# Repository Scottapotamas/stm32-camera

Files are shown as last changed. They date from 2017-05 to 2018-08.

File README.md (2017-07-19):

# stm32-camera

Existing products are either cameras which lack resolution and image quality (640x480 security cams that happen to have UART outputs), or are higher end expensive options geared towards computer vision for embedded hardware (openMV, PixyCam, etc).

This project seeks to provide higher quality still photos or short low-fps videos in an integrated device, allowing for greater integration flexibility whilst minimising power consumption.

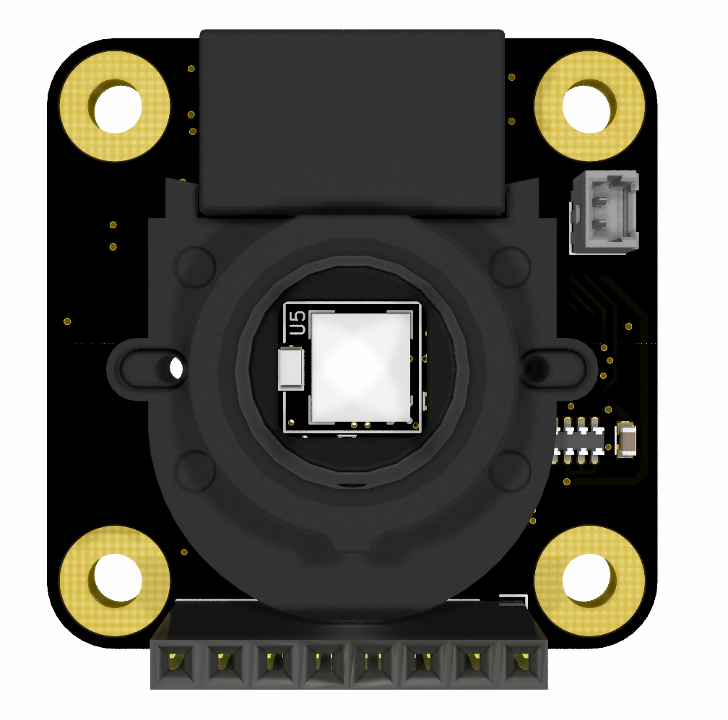
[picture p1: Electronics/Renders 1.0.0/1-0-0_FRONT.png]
Business at the front

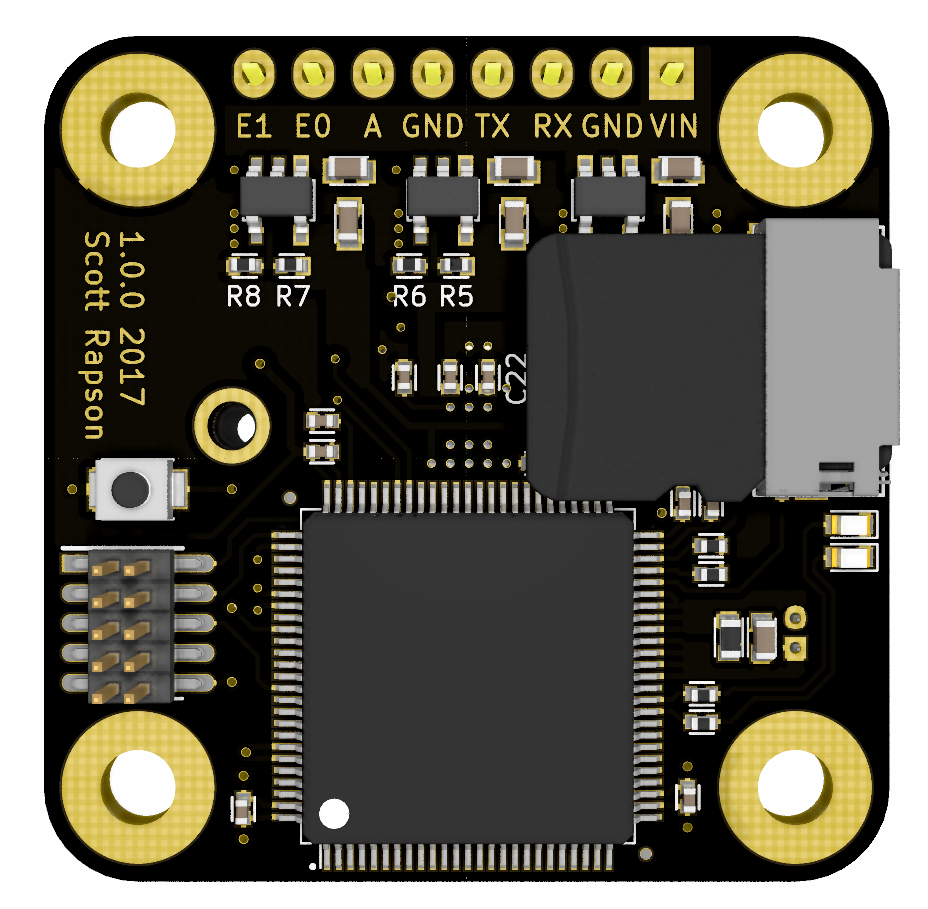
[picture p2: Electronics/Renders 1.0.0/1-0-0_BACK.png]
Party in the back


# Project Goals

- Sample a CMOS camera sensor using a microcontroller. Condition the data as appropriate, and hold images in memory.
- Allow upload of image data to the host over a serial, USB, or other connection.
- Aim to minimise current draw wherever possible, and design around the ability to 'deep-sleep' for maximum power savings.
- Support a wide range of lenses for different application requirements.
- Allow the host to control functionality such as exposure, capture modes, resolution, and power saving functionality.
- Cost less than $65
- Provide source for interfacing a host device like an Arduino/STM32.
- Provide software sources for the camera board to allow modified behaviour.

# Bonus Features

- Control either an onboard or off-board LED flash. Use a DAC output to drive it for variable brightness.
- Control a IR filter switch mechanism to add or subtract IR filtering automatically at night.
- Include hardware light sensing to detect ambient light without use of the camera (for IR filter switch, dynamic flash brightness, etc).
- Ability to store images or image sequences on disk, and/or copy them off later when the action dies down.

# Approach

- Small 32x32mm PCB with camera sensor, lens mount (uses 20mm spaced M2 screws), microcontroller.
- STM32F4 microcontroller interfaces to the sensor and provides power management, filter swaps, storage etc.
- The IO pinout is 2.54mm 8-way through hole. Accepts 4-14V DC input power. Has UART, and 3 high feature set expansion IO.
- Mounting hole pattern is somewhat backwards compatible with 28mm spaced M3 holes.

# Hardware Overview

- Its a 4 layer board due to the density of the fanout and smaller board package. 
- Min track width/clearance is 0.22mm and min via is 0.35mm. No blind or buried vias.
- While a bit tight, it should be fine with better 'budget' Chinese fabs. OSHPark would have absolutely no issues with it.
- Specific notes are in [the electronics folder](Electronics)

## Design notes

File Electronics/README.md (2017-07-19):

# Electronics Notes

General implementation notes during assignment and schematic capture. These are notes which don't make it onto the schematic due to length or relevance. Hopefully they might be useful during software dev.

# Microcontroller Pin Assignment

- I2C2 peripheral is used for SSCB interface (configuration registers).
- MCO (PA8) is used for the camera XCLK clock. Should clock at 24Mhz typical, 6Mhz minimum. This can be the HSI, HSE, a timer, etc.
- DCMI interface is used for main camera connection (includes HSYNC/VSYNC/PIXCK pins etc)
- PCLK is the camera strobe for 8-bit data on rising edge.
- PWDN is the camera power down signal (active high). Connected to PE3.
- RES is camera reset signal (active low). Connected to PE2
- SDIO interface is used in 4-bit mode for SD card. In theory, we should be able to write images to the SD card at highish speed, then allow the host to pull them off later if needed.
- SWD with SWO is enabled explicitly. Plan on using CORTEX 10-pin header.
- HSE clock included. Probably use a 16MHz CERALOCK instead of usual 8MHz?
- DAC2 is proposed for use with a flash driver. Ideally don't use PWM as switching noise is potentially visible, but that same pin can also be an analog input, PWM output or general GPIO.

# Sensor Specifics

## Power Down Options

| Hardware Control  | Software Control |
| --- | --- |
| PWDN is pulled high to stop the clock  | i2c commands available but doesn't stop everything (clocks) |
| Power draw is apparently 15uA.  | Registers are retained but draws 1mA.  |

Later on in the datasheet, this is conflicted by:

> For OV2640, there have big power down current, so power down mode is not supported by OV2640 for power saving.

The lower voltage LDO's have their EN line connected to the micro for more granular/forceful control.
I'll likely just use hardware control as long as it configures fast enough.

## Reset

A full hardware reset is performed when RESETB goes low.

There is also reset via the i2c interface.

## Other lines

- The datasheet states that strobe mode allows it to operate with an external flash and(/or?) LED. 
- The pinmap guide states this defaults as an input, but is the flash control output.
- A STM32 GPIO is connected instead of flash driver (at least to know if the camera wants a flash, probably redundant info by the time we see it)

# SD Card

# IR Cut Filter Switcher

As far as I can tell, its a bistable solenoid which moves the IR cut filter infront or away from the sensor.

## Theory

The [aliexpress page I got my samples from](https://www.aliexpress.com/item/HD-3MP-IR-CUT-filter-M12-lens-Metal-mount-double-filter-switcher-for-cctv-camera-IRCUT/32785570950.html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 ) has no real information other than images (but hey, $2.50AUD).

This [ebay page](http://www.ebay.com/itm/400938137287) seems to have more info (copied below)

- Working Voltage: 5V-18V
- Rated Current: 0.2A
- Screw thread interface: M12 Mount (MTV / C)
- Switcher Type: Pendulum Switcher
- Filter: Phosphate Filter
- Glass Size: 11*9.3mm
- Hole Spacing: 20mm
- Total length: 30mm. Inner Diameter: 15mm

I found another page with similar looking units which states the following:

- Start voltage: 1.8V±10%
- Applied voltage: 3.0V±10%
- Driver pulse width: 50ms
- Trigger current: 100mA or less
- Working current: 200mA or less

~~If the filter needs to be held in place during aquisition then some interesting software might need to manage the power consumption cleverly.~~ Pendulum switching means a short pulse high or low to set and forget. Drive with inverted polarity to change back.
This seems to vary between modules. Some of the other samples I received later *are* spring loaded.

It appears the units I recieved use a 1.25mm pitch molex(?) 2-pin connector. 
I'm pretty sure its molex because locking tab instead of slot. 
Seems like a Picoblade connector.

## Testing

Tests with bench supply show switching latches setting after power is removed.

With the supply set to 3.000V, the minimum current which triggers a full switch is 60mA. At 40mA and above, it appears to half-hold and reset on removal of power. Below 40mA nothing happens.

Switching would not occur at 2.0V. At 2.5V 50mA was able to activate the shutter, but 60-70mA was more reliable.

At 3.250V (rough design target for regulator and hence micro VDD) 45mA was enough to trigger a switch but sounded 'slower'. It seems the solenoid will draw 54mA, or 0.175W.

As some of these cameras will be in potentially extreme outdoor environments, a switching unit was cooled to -10°C and tested. 
At the same 3.250V, it requires 60mA to switch (0.195W). 

## Decision

It is unclear how the power requirements might change with manufacturing tolerances, temp cycling etc. Effects such as stiction etc haven't been tested for.

A 100mA spec'ed H-Bridge driver or equiv is probably the route to go.

As this eats a lot of room on the board using even small H-bridge drivers, and cost is a luxury, I'm strongly considering using multiple parallel GPIO pins (shared port for bitwise simultaneous control) to allow for push pull drive. As we only need short impulses this seems reasonable.

Unclear if the body diodes in the micro will be happy with this arrangement.

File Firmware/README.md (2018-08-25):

# Software Notes

General implementation notes during development. Some hardware related notes are built in here for people unfamiliar with STM32 or the programming ecosystem for ARM micros.

# Software Development and Debugging

## Toolchain and Install

I use the [SW4 System Workbench for STM32](http://www.openstm32.org/System+Workbench+for+STM32) for development and debugging. Follow the install instructions from openstm and everything should be reasonably easy to get working. The Eclipse project includes the config file for the debugging setup with both STLink and J-Link.

If you use a STLink programmer (either standalone or on a ST Discovery/Nucleo board) this should be all you need.

I use the SEGGER J-Link, so installing the J-Link software and the Eclipse plugin (Use Eclipse's "Install new software" and use the http://gnu-mcu-eclipse.netlify.com/v4-neon-updates source. I only install the J-Link plugin)

## Importing and navigating source

Import the project file in the stm32-camera folder. Code in [Src](stm32-camera\Src) is applicable to the project, everything else is either Eclipse or CubeMX generated. 

The software is based heavily on the framework I use at work, and uses a (custom) simple task scheduler and series of (HSM) state machines. The app_state_machines folder contains the highest level tasks and handles events.

app_drivers contains the mid-level functional code to handle individual software level tasks like or manage a series of hardware interfaces (controlling the camera requires use of the DCMI, GPIO and timer/mco functions for example).

app_hal is the 'low-level' hardware interface code. This mostly wraps the STM32 HAL library calls in human friendly functions for convenience. This layer can/should be split away form the rest of the code to provide unit tests, or reduce the effort for porting to other platforms etc.

## Flashing/Debugging Hardware

The board has a CORTEX 1.25mm pitch 2x5 connector for flashing and debugging over SWD. Pinout is below. Pin 7 is designed as the locating pin/key, and some connectors or headers don't have the pin/socket.

| Row 1 Pins | Row 2 Pins |
| --- | --- |
| 1 - VTref | 2 - SWDIO		|
| 3 - GND 	| 4 - SWDCLK	|
| 5 - GND 		| 6 - SWO		|
| 7 - Key/NC	| 8 - NC		|
| 9 - GNDDetect | 10 - NRST		|

I use a J-Link programmer, but the ST-Link/VS ISOL is also another choice I like which uses the same 20-pin jtag header.

Adafruit sell a [suitable cable](https://www.adafruit.com/product/1675), and [adaptor board](https://www.adafruit.com/product/2094) for standard 2.54mm 20-pin. I got an [adapter from OLIMEX](https://www.olimex.com/Products/ARM/JTAG/ARM-JTAG-20-10/) which is a bit nicer for direct connection to the programmer.

Using a STM32 discovery as a programmer, or the cheap chinese STLink clones will also work, but you will need to make a suitable cable.

## STM32 CubeMX

CubeMX is designed to take the effort out of setting up and configuring the peripherals and pins on STM32 micros. This is pretty standard in many STM based projects and should be easy enough to follow.

If pinouts are being changed or settings modified, make sure the changes are actually reflected in the app_hal source as I don't use the CubeMX generated wrappers for init etc. By rolling (mostly) the same code in my own hal layer, there are fewer issues with regenerating cubemx and allows for dynamic init/deinit of peripherals to reduce power when they are unused.

## Unit Tests

TODO: describe how to run tests

TODO: actually add a testing framework and write tests...

## Firmware Flashing without SWD

The microcontroller supports firmware updates using the internal read-only bootloader which is present on all STM32 chips. This functionality means the board is 'unbrickable'. This same functionality allows a 'host' microcontroller to update the camera board firmware in the field.

Normally the BOOT0 pin is held high during startup and the micro will enter the bootloader. On this board, the micro has the ability to enter the bootloader from software, which is done by charging a capacitor then calling for a reboot. The cap holds BOOT0 high long enough for the STM upgrade utility to start.

The microcontroller can be commanded to enter this mode through the command line. TODO:by holding the user-button for 5 seconds during boot.

A UART cable can be used with the [ST Demonstration Flasher32 Application DB2875](http://www.st.com/en/development-tools/flasher-stm32.html) to perform firmware updates with a PC.

The protocol for the bootloader is defined in the [ST AN3155 appnote](http://www.st.com/content/ccc/resource/technical/document/application_note/51/5f/03/1e/bd/9b/45/be/CD00264342.pdf/files/CD00264342.pdf/jcr:content/translations/en.CD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).

If you've flashed some software that prevents the micro from being able to start the upgrade proceedure, you can manually force BOOT0 high by conecting the outside side of C28 to 3.3V (or use SWD and a real programmer).

___

# Clock Speed and Performance

The F429 was originally selected due to DCMI, SDIO peripherals, and best internal RAM/$ for the QFP100 package.

As one of the goals of this board is low quiescent power consumption, I've made an effort to build tools early on to validate power usage.

## SLEEP Mode

Low hanging fruit (micro into sleep mode when waiting for events) makes the largest difference, cutting the 220mW starting draw to ~110mW. 

TODO: Consider not waking on systick interupts?

## 'Underclocking' the core

By adding a CPU load measurement, I was able to watch task requirements and processing time, and drop the clock speed of the micro.

By measuring the power consumption (micro powered directly from lab supply) against clock frequency I noticed how substantial savings could be for idle operation. 

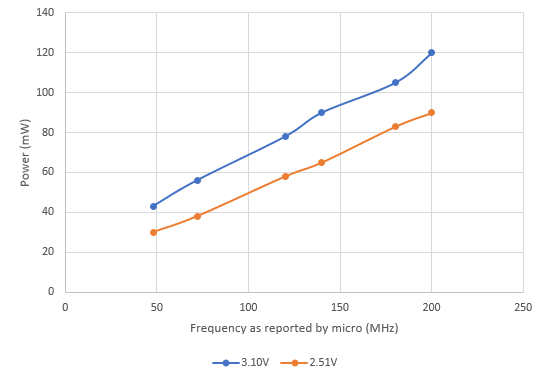
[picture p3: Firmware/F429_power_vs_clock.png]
Core Speed vs Power


From here, dynamic clock speed handling was developed to help reduce wasted energy when we aren't doing much.

## STOP mode

When we know (or the host controlling us) that we aren't needed, STOP mode represents another drop in average idle consumption by stopping clocks and peripherals altogether.

Intend for wake on the USART1 interupt. Need to profile power consumption and startup times to see if this is acceptable.

# SD Card

We use the SDIO interface in 4-bit mode.

This thread discusses using DMA for high performance non-blocking use.
https://community.st.com/thread/39133-high-performance-sdiosdmmc-driver-using-dma-for-freertos-anyone

Also this tutorial: http://thehackerworkshop.com/?p=1103

Detection relies on the internal pullup on that GPIO pin.

# Other notes

https://github.com/nothings/stb

Seems like a possible option for direct jpeg manipulation.

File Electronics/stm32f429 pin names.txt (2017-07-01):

TRACECLK/SPI4_SCK/SAI1_MCLK_A/ETH_MII_TXD3/FMC_A23
TRACED0/SAI1_SD_B/FMC_A19
TRACED1/SPI4_NSS/SAI1_FS_A/FMC_A20/DCMI_D4/LCD_B0
TRACED2/TIM9_CH1/SPI4_MISO/SAI1_SCK_A/FMC_A21/DCMI_D6/LCD_G0
TRACED3/TIM9_CH2/SPI4_MOSI/SAI1_SD_A/FMC_A22/DCMI_D7/LCD_G1
VBAT
EVENTOUT
EVENTOUT
EVENTOUT
VSS
VDD
EVENTOUT
EVENTOUT
NRST
OTG_HS_ULPI_STP/FMC_SDNWE
ETH_MDC/SPI2_MISO/I2S2ext_SD/OTG_HS_ULPI_DIR/ETH_MII_TXD2/FMC_SDNE0
SPI2_MISO/I2S2ext_SD/OTG_HS_ULPI_DIR/ETH_MII_TXD2/FMC_SDNE0
SPI2_MOSI/I2S2_SD/OTG_HS_ULPI_NXT/ETH_MII_TX_CLK/FMC_SDCKE0
VDD
VSSA
VREF+
VDDA
TIM2_CH1/TIM2_ETR/TIM5_CH1/TIM8_ETR/USART2_CTS/UART4_TX/ETH_MII_CRS
TIM2_CH2/TIM5_CH2/USART2_RTS/UART4_RX/ETH_MII_RX_CLK/ETH_RMII_REF_CLK
TIM2_CH3/TIM5_CH3/TIM9_CH1/USART2_TX/ETH_MDIO
TIM2_CH4/TIM5_CH4/TIM9_CH2/USART2_RX/OTG_HS_ULPI_D0/ETH_MII_COL/LCD_B5
VSS
VDD
SPI1_NSS/SPI3_NSS/I2S3_WS/USART2_CK/OTG_HS_SOF/DCMI_HSYNC/LCD_VSYNC
TIM2_CH1/TIM2_ETR/TIM8_CH1N/SPI1_SCK/OTG_HS_ULPI_CK
TIM1_BKIN/TIM3_CH1/TIM8_BKIN/SPI1_MISO/TIM13_CH1/DCMI_PIXCLK/LCD_G2
TIM1_CH1N/TIM3_CH2/TIM8_CH1N/SPI1_MOSI/TIM14_CH1/ETH_MII_RX_DV/ETH_RMII_CRS_DV
ETH_MII_RXD0/ETH_RMII_RXD0
ETH_MII_RXD1/ETH_RMII_RXD1
TIM1_CH2N/TIM3_CH3/TIM8_CH2N/LCD_R3/OTG_HS_ULPI_D1/ETH_MII_RXD2
TIM1_CH3N/TIM3_CH4/TIM8_CH3N/LCD_R6/OTG_HS_ULPI_D2/ETH_MII_RXD3
EVENTOUT
TIM1_ETR/UART7_Rx/FMC_D4
TIM1_CH1N/UART7_Tx/FMC_D5
TIM1_CH1/FMC_D6
TIM1_CH2N/FMC_D7
TIM1_CH2/SPI4_NSS/FMC_D8/LCD_G3
TIM1_CH3N/SPI4_SCK/FMC_D9/LCD_B4
TIM1_CH3/SPI4_MISO/FMC_D10/LCD_DE
TIM1_CH4/SPI4_MOSI/FMC_D11/LCD_CLK
TIM1_BKIN/FMC_D12/LCD_R7
TIM2_CH3/I2C2_SCL/SPI2_SCK/I2S2_CK/USART3_TX/OTG_HS_ULPI_D3/ETH_MII_RX_ER/LCD_G4
TIM2_CH4/I2C2_SDA/USART3_RX/OTG_HS_ULPI_D4/ETH_MII_TX_EN/ETH_RMII_TX_EN/LCD_G5
VCAP_1
VDD
TIM1_BKIN/I2C2_SMBA/SPI2_NSS/I2S2_WS/USART3_CK/CAN2_RX/OTG_HS_ULPI_D5/ETH_MII_TXD0/ETH_RMII_TXD0/OTG_HS_ID
TIM1_CH1N/SPI2_SCK/I2S2_CK/USART3_CTS/CAN2_TX/OTG_HS_ULPI_D6/ETH_MII_TXD1/ETH_RMII_TXD1
TIM1_CH2N/TIM8_CH2N/SPI2_MISO/I2S2ext_SD/USART3_RTS/TIM12_CH1/OTG_HS_DM
RTC_REFIN/TIM1_CH3N/TIM8_CH3N/SPI2_MOSI/I2S2_SD/TIM12_CH2/OTG_HS_DP
USART3_TX/FMC_D13
USART3_RX/FMC_D14
USART3_CK/FMC_D15/LCD_B3
USART3_CTS/FMC_A16
TIM4_CH1/USART3_RTS/FMC_A17
TIM4_CH2/FMC_A18
TIM4_CH3/FMC_D0
TIM4_CH4/FMC_D1
TIM3_CH1/TIM8_CH1/I2S2_MCK/USART6_TX/SDIO_D6/DCMI_D0/LCD_HSYNC
TIM3_CH2/TIM8_CH2/I2S3_MCK/USART6_RX/SDIO_D7/DCMI_D1/LCD_G6
TIM3_CH3/TIM8_CH3/USART6_CK/SDIO_D0/DCMI_D2
MCO2/TIM3_CH4/TIM8_CH4/I2C3_SDA/I2S_CKIN/SDIO_D1/DCMI_D3
MCO1/TIM1_CH1/I2C3_SCL/USART1_CK/OTG_FS_SOF/LCD_R6
TIM1_CH2/I2C3_SMBA/USART1_TX/DCMI_D0
TIM1_CH3/USART1_RX/OTG_FS_ID/DCMI_D1
TIM1_CH4/USART1_CTS/CAN1_RX/LCD_R4/OTG_FS_DM
TIM1_ETR/USART1_RTS/CAN1_TX/LCD_R5/OTG_FS_DP
JTMS-SWDIO
VCAP_2
VSS
VDD
JTCK-SWCLK
JTDI/TIM2_CH1/TIM2_ETR/SPI1_NSS/SPI3_NSS/I2S3_WS
SPI3_SCK/I2S3_CK/USART3_TX/UART4_TX/SDIO_D2/DCMI_D8/LCD_R2
I2S3ext_SD/SPI3_MISO/USART3_RX/UART4_RX/SDIO_D3/DCMI_D4
SPI3_MOSI/I2S3_SD/USART3_CK/UART5_TX/SDIO_CK/DCMI_D9
CAN1_RX/FMC_D2
CAN1_TX/FMC_D3
TIM3_ETR/UART5_RX/SDIO_CMD/DCMI_D11
SPI2_SCK/I2S2_CK/USART2_CTS/FMC_CLK/DCMI_D5/LCD_G7
USART2_RTS/FMC_NOE
USART2_TX/FMC_NWE
SPI3_MOSI/I2S3_SD/SAI1_SD_A/USART2_RX/FMC_NWAIT/DCMI_D10/LCD_B2
USART2_CK/FMC_NE1/FMC_NCE2
JTDO/TRACESWO/TIM2_CH2/SPI1_SCK/SPI3_SCK/I2S3_CK
NJTRST/TIM3_CH1/SPI1_MISO/SPI3_MISO/I2S3ext_SD
TIM3_CH2/I2C1_SMBA/SPI1_MOSI/SPI3_MOSI/I2S3_SD/CAN2_RX/OTG_HS_ULPI_D7/ETH_PPS_OUT/FMC_SDCKE1/DCMI_D10
TIM4_CH1/I2C1_SCL/USART1_TX/CAN2_TX/FMC_SDNE1/DCMI_D5
TIM4_CH2/I2C1_SDA/USART1_RX/FMC_NL/DCMI_VSYNC
BOOT0
TIM4_CH3/TIM10_CH1/I2C1_SCL/CAN1_RX/ETH_MII_TXD3/SDIO_D4/DCMI_D6/LCD_B6
TIM4_CH4/TIM11_CH1/I2C1_SDA/SPI2_NSS/I2S2_WS/CAN1_TX/SDIO_D5/DCMI_D7/LCD_B7
TIM4_ETR/UART8_RX/FMC_NBL0/DCMI_D2
UART8_Tx/FMC_NBL1/DCMI_D3

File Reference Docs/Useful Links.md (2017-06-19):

# Omnivision documentation

- Found the 'confidential' OV hardware and software appnotes, along with the SSCB (i2c like) settings interface.
- Found some unattributed c code which has the best register maps I've found so far.
- Won't run on hardware, but great reference for control over camera functions.

# OV2640 Camera Module under ChibiOS on the STM32F4-Discovery Board

http://www.elektricks.net/ov2640-camera-module-under-chibios-on-the-stm32f4-discovery-board/

- Provided source
- Uses chibiOS
- Uses DCMI, shows pinout and wiring to F4 disco
- Blog post archived in .zip.

# OV2640 Camera module on STM32 (without DCMI interface)

http://qyx.krtko.org/projects/ov2640_stm32/
https://github.com/iqyx/ov2640-stm32

- Main.c code in ref folder.
- Blog archived in zip.
- Uses chibiOS
- Doesn't use DCMI (because chibiOS had poor support for it back then)
- Uses DMA, discusses i2c config.

# OV2640 Linux driver

- Has additional notes for register settings etc.
- Source .c in folder.

# General Notes

0xFF 0xD8 is the start of a JPEG frame.
0xFF 0xD9 is the end of the JPEG frame.

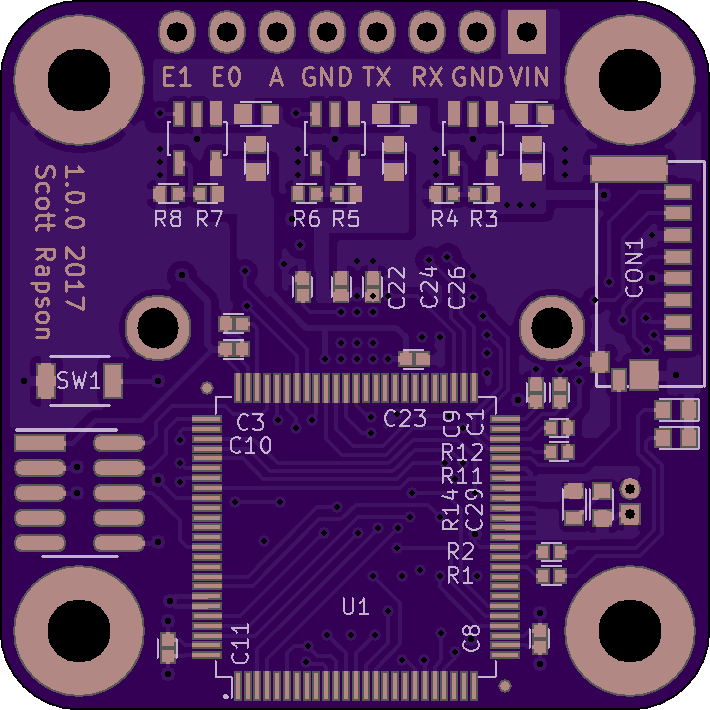
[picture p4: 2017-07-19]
Electronics/Renders 1.0.0/osh-check-back.png

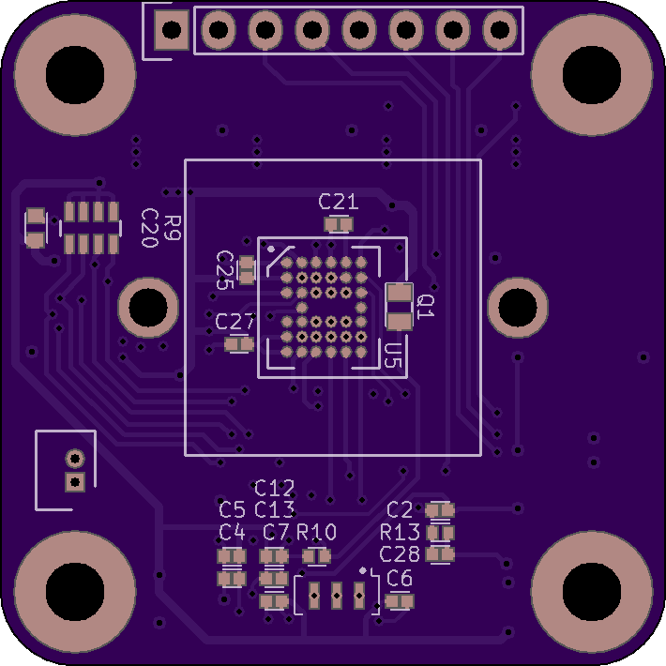
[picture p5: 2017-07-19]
Electronics/Renders 1.0.0/osh-check-front.png

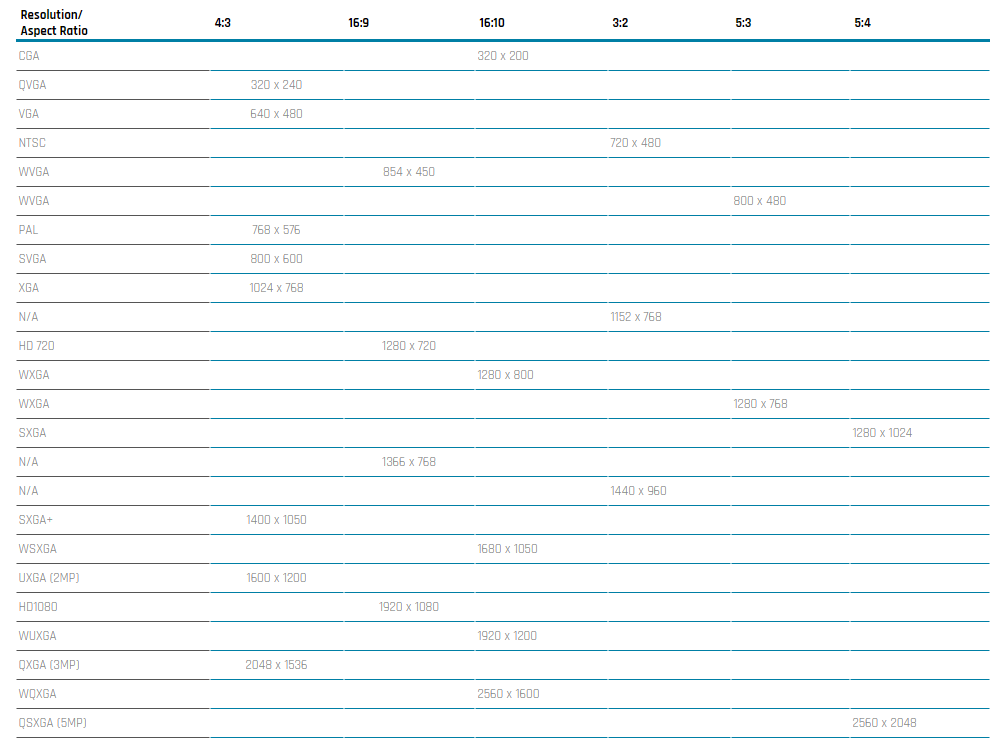
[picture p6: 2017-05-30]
Reference Docs/Resolution table.PNG

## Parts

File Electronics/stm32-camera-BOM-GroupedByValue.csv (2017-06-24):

Title:
Rev: | A
Source: | F:\Projects\stm32-camera\Electronics\stm32-camera.sch
Date: | 25/06/2017 1:23:17 AM
Component Count: | 53
Ref | Qty | Value | Description | Manf | Manf# | Installed | Footprint
C1, C3, C4, C12, C20, C24 | 6 | 1UF_X5R_1005M | CAP, MLCC, X5R, 1UF, 35V, 0402, 1005M | TDK | C1005X5R1V105K050BC |  | CAPC1005X60N
C14, C15, C16, C17, C18, C19 | 6 | 2.2UF_X7R_1608M | CAP, MLCC, X7R, 2.2UF, 50V, 0603 | MURATA | GRM188R61H225KE11D |  | CAPC1608X90L
C2, C5, C6, C7, C8, C9, C10, C11, C13, C21, C22, C25, C26, C27 | 14 | 100NF_X7R_1005M | CAP, MLCC, X7R, 100NF, 50V, 0402, 1005M | TDK | CGA2B3X7R1H104K050BB |  | CAPC1005X60N
C23 | 1 | 4.7UF_X5R_1608M | CAP, MLCC, X5R, 4.7UF, 16V, 0603 | TDK | C1608X5R1C475K080AC |  | CAPC1608X90L
CON1 | 1 | MOLEX_47309-2651 | Molex SMD Compact Micro SD Card Connector, Push-Pull Insertion, Floating Card | MOLEX | 47309-2651 |  | MOLEX_47309-2651
D1 | 1 | LED_GREEN_1608M | DIALIGHT ChipLED Green, 0603, 1608M | DIALIGHT | 5988070107F |  | LEDC1608X80L40N
D2 | 1 | LED_RED_1608M | DIALIGHT ChipLED Red, 0603, 1608M | DIALIGHT | 5988010107F |  | LEDC1608X80L40N
MP1 | 1 | M12_LENS_MOUNT_IR_SWITCHNG | M12x0.5 Lens Mount, Metal Body, M2-20mm holes, IR and Daylight Filter, Switchable | NOVOXY | UNKNOWN |  | M12x0.5_LENS_MOUNT_IR_SWITCHNG
P1 | 1 | HEADER_MALE_2MM_01X06 | Board-To-Board Connector, 2 mm, 6 Contacts, Header, Male, M22 Series, Through Hole, 1 Rows | HARWIN | M22-2510605 |  | HDRV6W50P200_6X1_1200X200H400
P2 | 1 | MOLEX_PICO_PTH_VERT_2_WAY | CONNECTOR, HEADER, 2POS, 1ROW, 1.25MM, PICOBLADE | MOLEX | 53047-0210 |  | MOLEX_PICOBLADE_53047-0210
Q1 | 1 | VEMT3700 | PHOTO TRANSISTOR, Vishay, NPN, 120degrees, 2-Pin PLCC package | VISHAY | VEMT3700-GS08 |  | VISHAY_VEMT3700N
R1, R2 | 2 | 1K_1005M | RESISTOR, THICK FILM, 1K, 63mW, 1%, 0402, 1005M | VISHAY | CRCW04021K00FKED |  | RESC1005X40N
R10 | 1 | 10K_1005M | RESISTOR, THICK FILM, 10K, 63mW, 1%, 0402, 1005M | VISHAY | CRCW040210K0FKED |  | RESC1005X40N
R11, R12 | 2 | 4K7_1005M | RESISTOR, THICK FILM, 4.7K, 125mW, 1%, 0402, 1005M | VISHAY | CRCW08054K70FKTA |  | RESC1005X40N
R3 | 1 | 51K_1005M | RESISTOR, THICK FILM, 51K, 63mW, 1%, 0402, 1005M | PANASONIC | ERA2AEB513X |  | RESC1005X40N
R4 | 1 | 82K_1005M | RESISTOR, THICK FILM, 82K, 100mW, 1%, 0402, 1005M | PANASONIC | ERJ2GEJ823X |  | RESC1005X40N
R5 | 1 | 47K_1005M | RESISTOR, THICK FILM, 47K, 63mW, 1%, 0402, 1005M | YAGEO | RC0402FR-0747KL |  | RESC1005X40N
R6 | 1 | 56K2_1005M | RESISTOR, THICK FILM, 56.2K, 63mW, 1%, 0402, 1005M | PANASONIC | ERA2AEB5622X |  | RESC1005X40N
R7 | 1 | 100K_1005M | RESISTOR, THICK FILM, 100K, 100mW, 1%, 0402, 1005M | PANASONIC | ERJ2RKF1003X |  | RESC1005X40N
R8 | 1 | 3K6_1005M | RESISTOR, THICK FILM, 3.6K, 100mW, 1%, 0402, 1005M | PANASONIC | ERJ2GEJ362X |  | RESC1005X40N
R9 | 1 | 47K_QUAD_ARRAY_1608M | RESISTOR, THICK FILM, 47K, 5%, 0603, 1608M, QUAD ARRAY | PANASONIC | EXB38V473JV |  | R_Array_Concave_4x1608M
U1 | 1 | STM32F429VET6 | ST STM32F429VET6, ARM Cortex-M4, 32bit, 180 MHz, 512 KB Flash, 256 KB SRAM, 100 Pins | ST MICROELECTRONICS | STM32F429VET6 |  | QFP50P1600X1600X160-100L25N
U2, U3, U4 | 3 | AP2210K-ADJ | AP2210K-ADJTRG1, Low Noise LDO Voltage Regulator, 300mA, Adjustable Voltage, 2%, 2.5 to 13.2 Vin, SOT23-5 | DIODES ZETEX | AP2210K-ADJTRG1 |  | SOT95P280X145-5L30N
U5 | 1 | OV02640-VL9A | OmniVision, Color, CMOS, Camera, 2.0 MP, UXGA 1/4" | OmniVision | OV02640-VL9A |  | OV2640_CSP_38
X1 | 1 | CSTCE8M00G55Z | Murata Ceramic Resonator, 8MHz Shear 33pF, 3-Pin SMT | Murata | CSTCE8M00G55Z-R0 |  | OSCSC-CSCTE-CERALOCK
X2 | 1 | SWD | Cortex-M Debug Connector, SWD, JTAG (Header 1.27mm pitch 10-way 2x5) | HARWIN | M50-3600542 |  | HARWIN_M50-3600542
Tool: | Eeschema (2017-03-19 revision 2637835a1)-makepkg
Script: | F:\Projects\ECAD\KiCad\scripts\BOM\bom\BOM-GroupedByValue.py

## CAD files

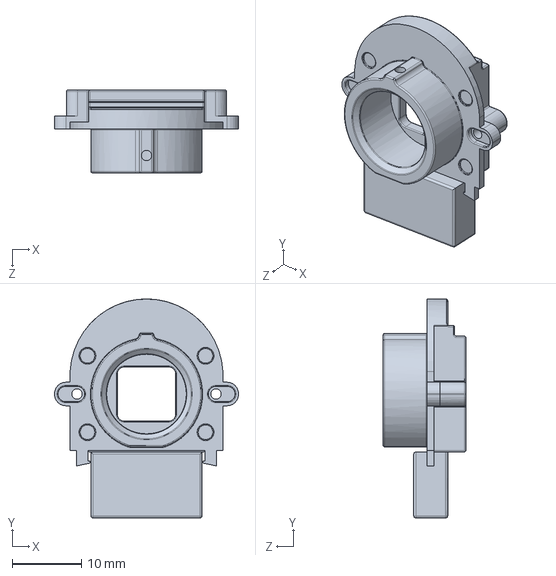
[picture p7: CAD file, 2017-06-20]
Mechanical/M12 Switchable IR Cut Filter Mount.SLDPRT
26.5 x 31.5 x 11.9 mm

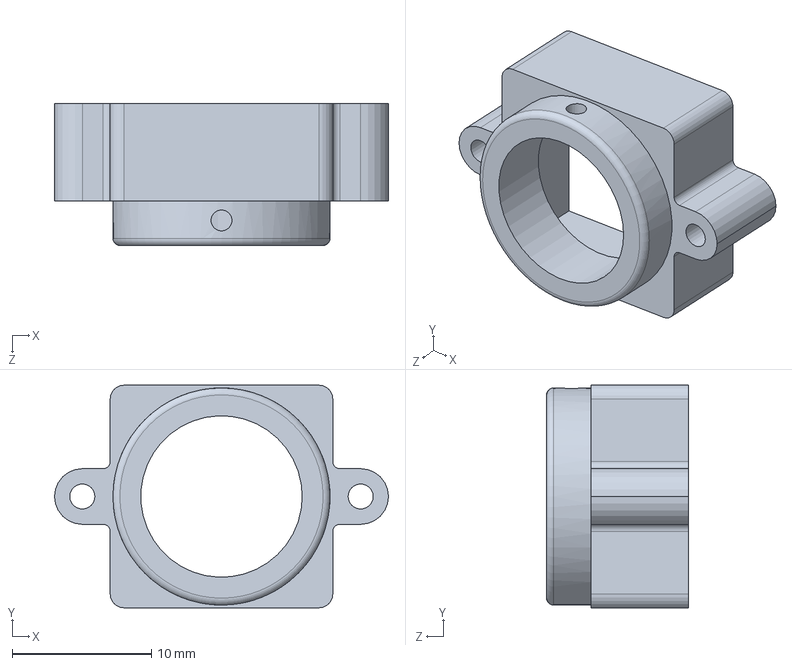
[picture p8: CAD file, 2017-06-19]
Mechanical/M12 Lens Mount Basic Block.SLDPRT
24.0 x 16.0 x 10.2 mm

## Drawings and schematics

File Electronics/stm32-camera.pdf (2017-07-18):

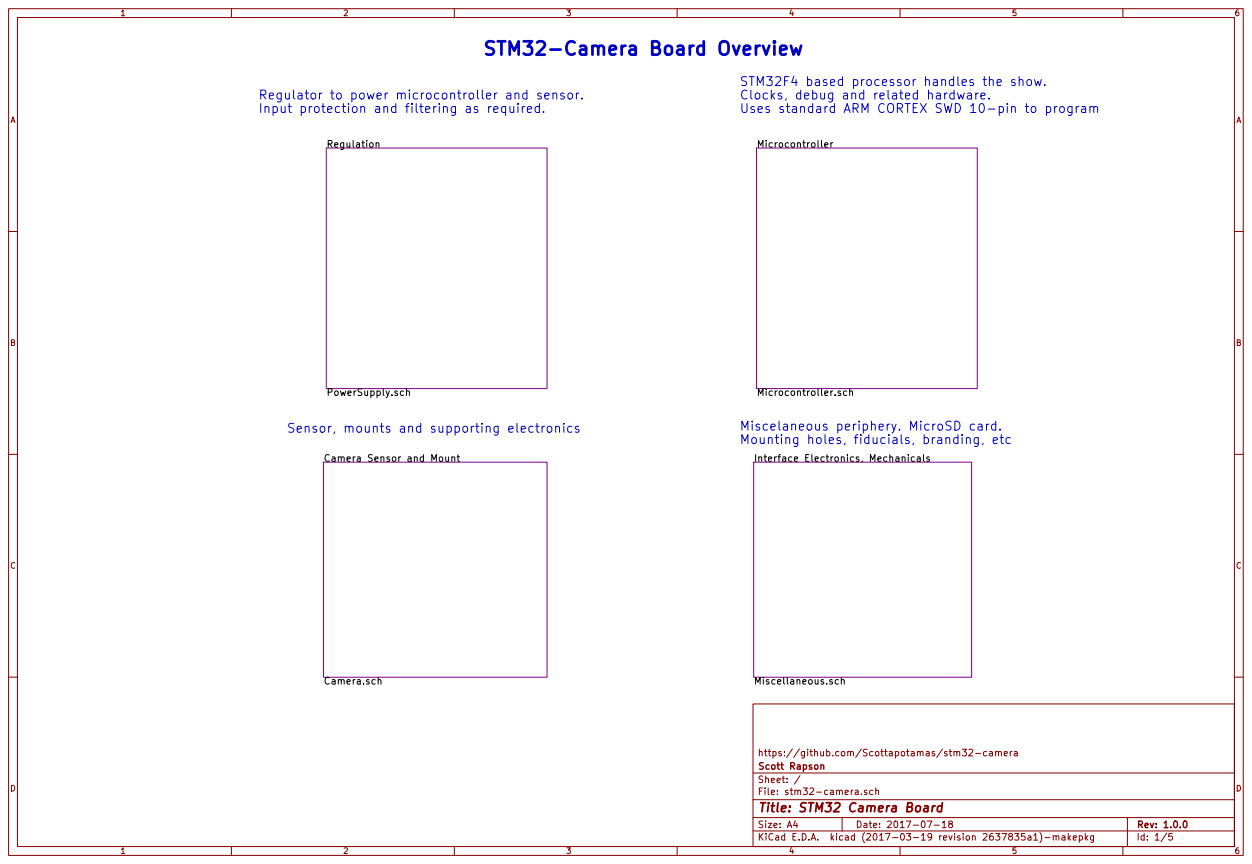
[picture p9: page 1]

Interface Electronics, Mechanicals Miscellaneous.sch STM32-Camera Board Overview

STM32F4 based processor handles the show.
Clocks, debug and related hardware.
Uses standard ARM CORTEX SWD 10-pin to program

Regulator to power microcontroller and sensor.
Input protection and filtering as required.

Microcontroller Microcontroller.sch Regulation

Sensor, mounts and supporting electronics

Miscelaneous periphery. MicroSD card.
Mounting holes, fiducials, branding, etc

Camera Sensor and Mount

https://github.com/Scottapotamas/stm32-camera
File: stm32-camera.sch Sheet: / Scott Rapson

Id: 1/5 Title: STM32 Camera Board

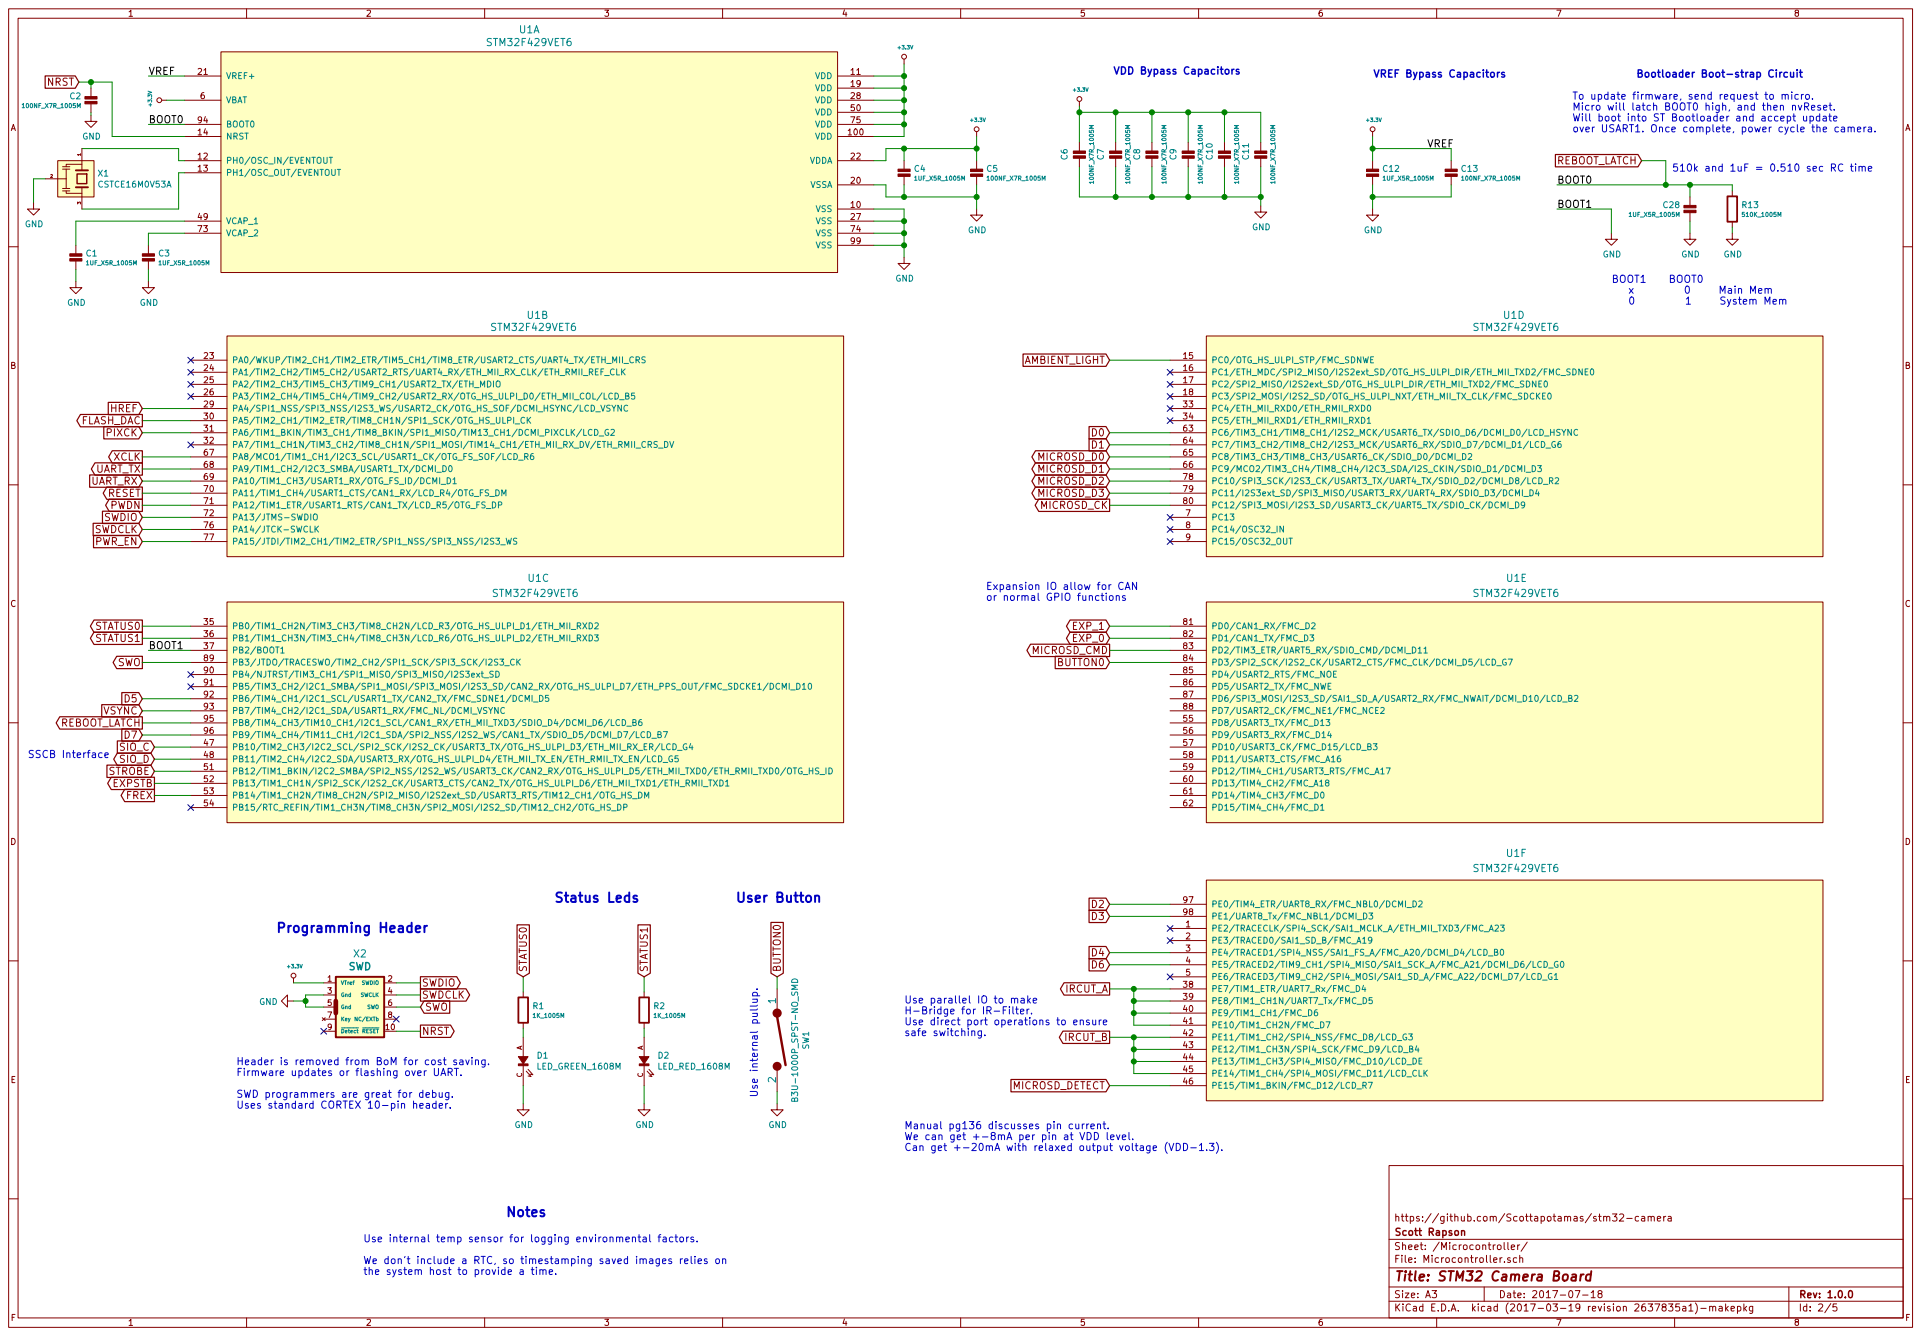
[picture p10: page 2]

Bootloader Boot-strap Circuit

BOOT1 GND To update firmware, send request to micro.
Micro will latch BOOT0 high, and then nvReset.
Will boot into ST Bootloader and accept update

over USART1. Once complete, power cycle the camera. GND

1UF_X5R_1005M510k and 1uF = 0.510 sec RC time

Expansion IO allow for CAN
or normal GPIO functions

User Button Use internal pullup.

Use parallel IO to make
H-Bridge for IR-Filter.
Use direct port operations to ensure

Header is removed from BoM for cost saving.
Firmware updates or flashing over UART.
SWD programmers are great for debug.
Uses standard CORTEX 10-pin header.

LED_RED_1608M Use internal temp sensor for logging environmental factors.

Manual pg136 discusses pin current.
We can get +-8mA per pin at VDD level.
Can get +-20mA with relaxed output voltage (VDD-1.3).

https://github.com/Scottapotamas/stm32-camera
File: Microcontroller.sch Sheet: /Microcontroller/ Scott Rapson

We don't include a RTC, so timestamping saved images relies on
the system host to provide a time.

Id: 2/5 Title: STM32 Camera Board

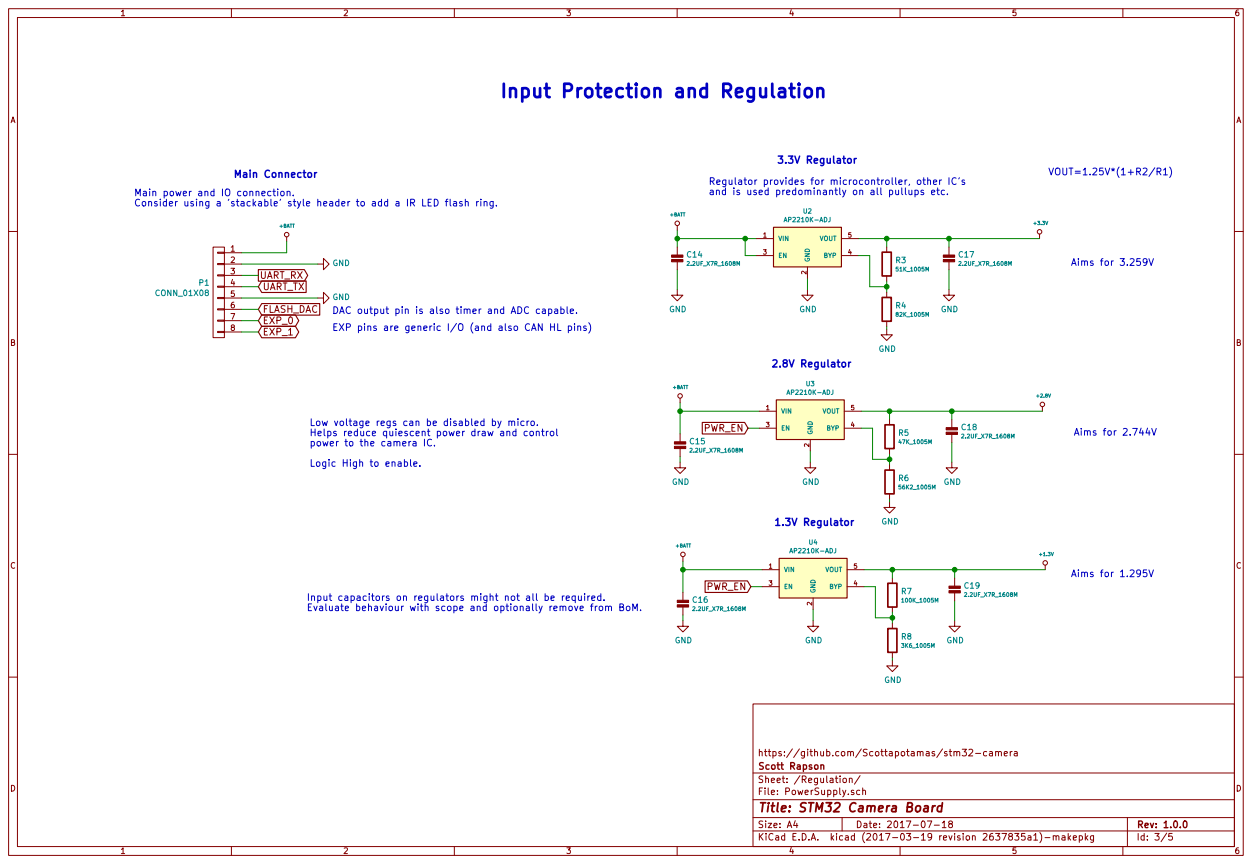
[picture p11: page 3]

Input Protection and Regulation

2 EN 3 BYP 4 VOUT 5 U2 AP2210K-ADJ VOUT=1.25V*(1+R2/R1) GND GND GND
2.2UF_X7R_1608M PWR_EN

Regulator provides for microcontroller, other IC's

Main power and IO connection.
Consider using a 'stackable' style header to add a IR LED flash ring. 1

EXP pins are generic I/O (and also CAN HL pins) GND
DAC output pin is also timer and ADC capable.

2 EN 3 BYP 4 VOUT 5 U3 AP2210K-ADJ

Low voltage regs can be disabled by micro.
Helps reduce quiescent power draw and control
power to the camera IC.
Logic High to enable.

2 EN 3 BYP 4 VOUT 5 U4 AP2210K-ADJ

Input capacitors on regulators might not all be required.
Evaluate behaviour with scope and optionally remove from BoM.

https://github.com/Scottapotamas/stm32-camera
Scott Rapson
Sheet: /Regulation/
File: PowerSupply.sch
Id: 3/5 Title: STM32 Camera Board

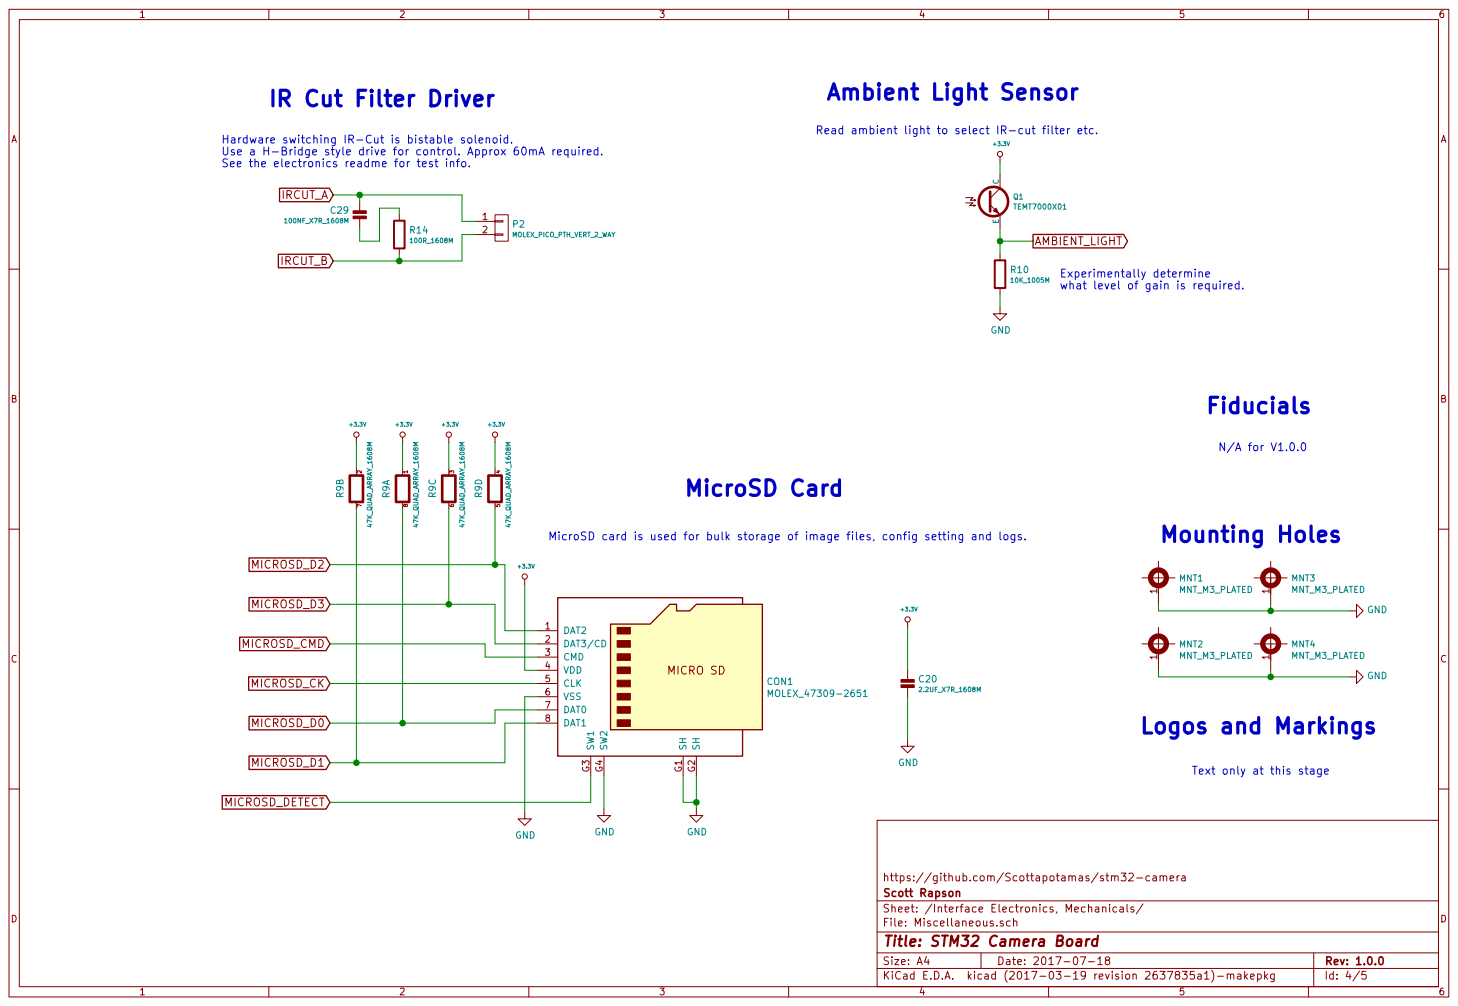
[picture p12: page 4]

Read ambient light to select IR-cut filter etc.

Hardware switching IR-Cut is bistable solenoid.
Use a H-Bridge style drive for control. Approx 60mA required.
See the electronics readme for test info.

what level of gain is required. R10
10K_1005M GND

1 MNT4 1MNT_M3_PLATED MNT2 MNT_M3_PLATED GND GND MICRO SD

Text only at this stage

https://github.com/Scottapotamas/stm32-camera
Scott Rapson
File: Miscellaneous.sch Sheet: /Interface Electronics, Mechanicals/
Id: 4/5 Title: STM32 Camera Board

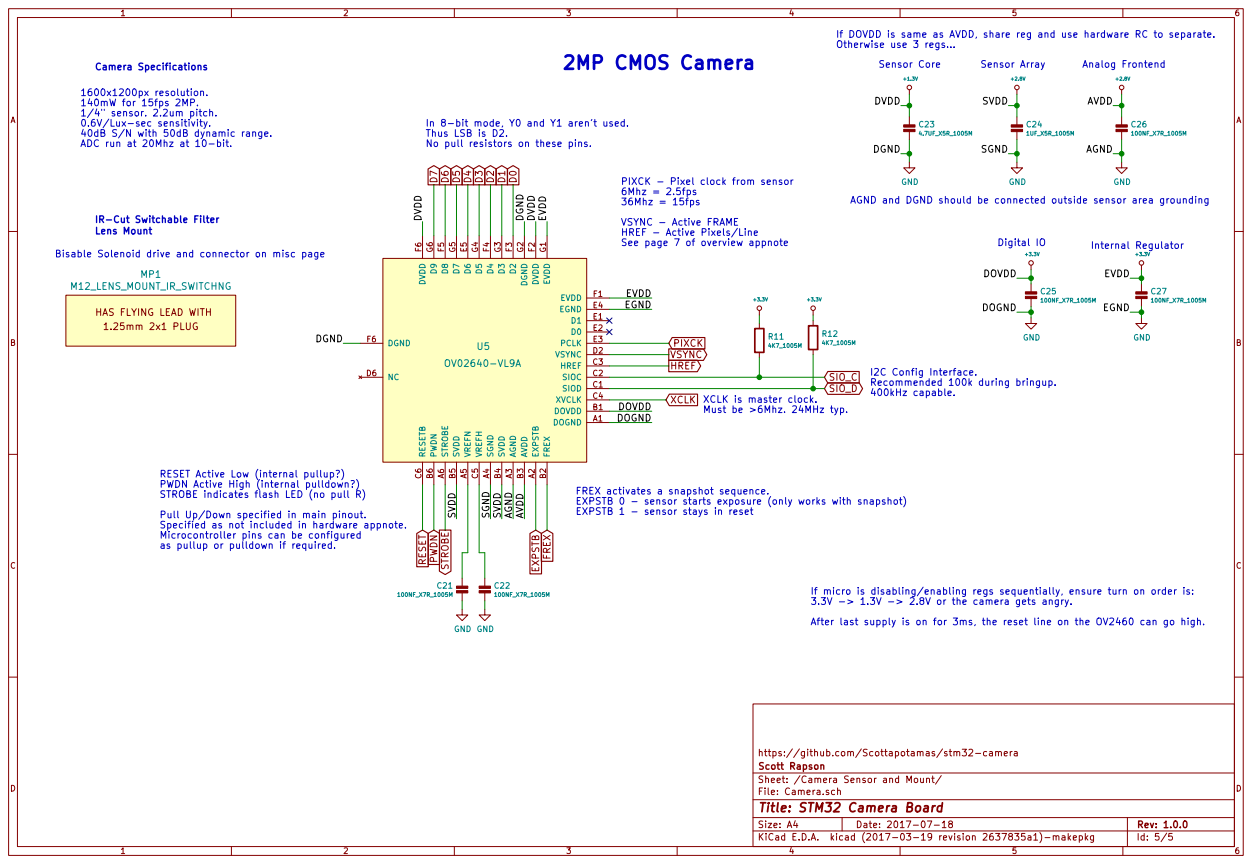
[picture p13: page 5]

If DOVDD is same as AVDD, share reg and use hardware RC to separate.

In 8-bit mode, Y0 and Y1 aren't used.
Thus LSB is D2.

100NF_X7R_1005M AGND and DGND should be connected outside sensor area grounding

See page 7 of overview appnote D7 D6 D5 D4 D3 D2 D1 D0

PIXCK - Pixel clock from sensor
6Mhz = 2.5fps
36Mhz = 15fps
VSYNC - Active FRAME
HREF - Active Pixels/Line

IR-Cut Switchable Filter Lens Mount Bisable Solenoid drive and connector on misc page

HAS FLYING LEAD WITH MP1 M12_LENS_MOUNT_IR_SWITCHNG

XCLK is master clock.

Must be >6Mhz. 24MHz typ. FREX EXPSTB

RESET Active Low (internal pullup?)
PWDN Active High (internal pulldown?)
STROBE indicates flash LED (no pull R)
Pull Up/Down specified in main pinout.
Specified as not included in hardware appnote.
Microcontroller pins can be configured
as pullup or pulldown if required.

FREX activates a snapshot sequence.
EXPSTB 0 - sensor starts exposure (only works with snapshot)
EXPSTB 1 - sensor stays in reset

If micro is disabling/enabling regs sequentially, ensure turn on order is:
3.3V -> 1.3V -> 2.8V or the camera gets angry.
After last supply is on for 3ms, the reset line on the OV2460 can go high.

https://github.com/Scottapotamas/stm32-camera
File: Camera.sch Sheet: /Camera Sensor and Mount/ Scott Rapson

Id: 5/5 Title: STM32 Camera Board

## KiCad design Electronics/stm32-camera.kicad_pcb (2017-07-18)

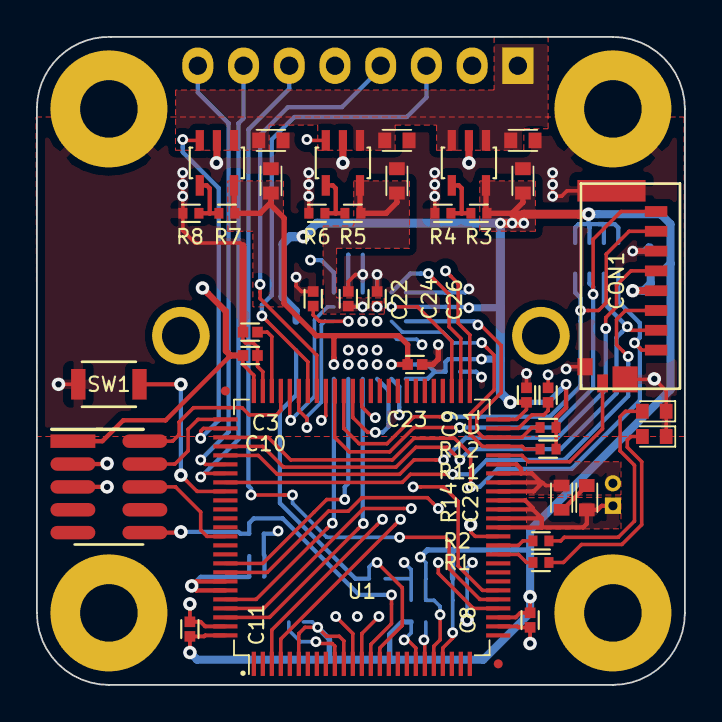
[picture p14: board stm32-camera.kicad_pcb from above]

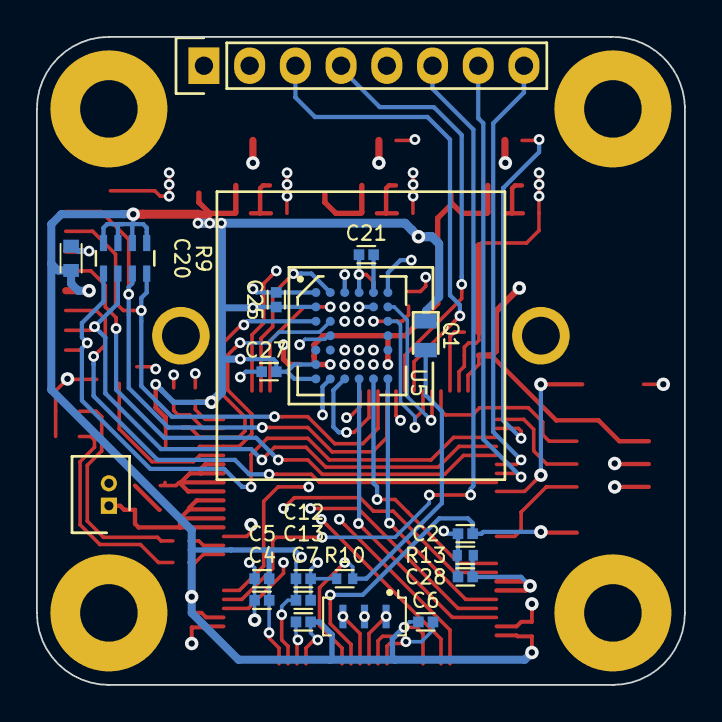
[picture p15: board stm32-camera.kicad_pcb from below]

Board: 4 copper layers, 36.0 x 36.0 mm, 62 parts (21 on the bottom side), 60 nets.

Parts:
C1, C3, C4, C12, C24, C28: 1UF_X5R_1005M; CAPC1005X60N
C2, C5, C6, C7, C8, C9, C10, C11, C13, C21, C22, C25, C26, C27: 100NF_X7R_1005M; CAPC1005X60N
C14, C15, C16, C17, C18, C19, C20: 2.2UF_X7R_1608M; CAPC1608X90L
C23: 4.7UF_X5R_1005M; CAPC1005X60N
C29: 100NF_X7R_1608M; CAPC1608X90L
CON1: MOLEX_47309-2651
D1: LED_GREEN_1608M; LEDC1608X80L40L
D2: LED_RED_1608M; LEDC1608X80L40L
MNT1, MNT2, MNT3, MNT4: MNT_M3_PLATED; MTGP650H330
MP1: M12_LENS_MOUNT_IR_SWITCHNG; M12x0.5_LENS_MOUNT_IR_SWITCHNG
P1: CONN_01X08; Socket_Strip_Straight_1x08
P2: MOLEX_PICO_PTH_VERT_2_WAY; MOLEX_PICOBLADE_53047-0210
Q1: TEMT7000X01; TEMT7000X
R1, R2: 1K_1005M; RESC1005X40N
R3: 51K_1005M; RESC1005X40N
R4: 82K_1005M; RESC1005X40N
R5: 47K_1005M; RESC1005X40N
R6: 56K2_1005M; RESC1005X40N
R7: 100K_1005M; RESC1005X40N
R8: 3K6_1005M; RESC1005X40N
R9: 47K_QUAD_ARRAY_1608M; R_Array_Concave_4x1608M
R10: 10K_1005M; RESC1005X40N
R11, R12: 4K7_1005M; RESC1005X40N
R13: 510K_1005M; RESC1005X40N
R14: 100R_1608M; RESC1608X50L
SW1: B3U-1000P_SPST-NO_SMD; B3U-1000P
U1: STM32F429VET6; QFP50P1600X1600X160-100L25L
U2, U3, U4: AP2210K-ADJ; SOT95P280X145-5L30N
U5: OV02640-VL9A; OV2640_CSP_38
X1: CSTCE16M0V53A; OSCSC-CSCTE-CERALOCK
X2: SWD; HARWIN_M50-3600542

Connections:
+1.3V: C19.1, C23.1, R7.1, U4.5, U5.F2, U5.F6
+2.8V: C18.1, C24.1, C26.1, R5.1, U3.5, U5.B3, U5.B4, U5.B5
+3.3V: C4.1, C5.1, C6.1, C7.1, C8.1, C9.1, C10.1, C11.1, C12.1, C13.1, C17.1, C20.1, C25.1, C27.1, CON1.4, Q1.C, R3.1, R9.1, R9.2, R9.3, R9.4, R11.1, R12.1, U1.6, U1.11, U1.19, U1.21, U1.22, U1.28, U1.50, U1.75, U1.100, U2.5, U5.B1, U5.F1, U5.G1, X2.1
+BATT: C14.1, C15.1, C16.1, P1.1, U2.1, U2.3, U3.1, U4.1
AMBIENT_LIGHT: Q1.E, R10.1, U1.15
BUTTON0: SW1.1, U1.84
D0: U1.63, U5.F3
D1: U1.64, U5.G3
D2: U1.97, U5.F4
D3: U1.98, U5.G4
D4: U1.3, U5.E5
D5: U1.92, U5.G5
D6: U1.4, U5.F5
D7: U1.96, U5.G6
EXPSTB: U1.52, U5.A2
EXP_0: P1.7, U1.82
EXP_1: P1.8, U1.81
FLASH_DAC: P1.6, U1.30
FREX: U1.53, U5.B2
GND: C1.2, C2.2, C3.2, C4.2, C5.2, C6.2, C7.2, C8.2, C9.2, C10.2, C11.2, C12.2, C13.2, C14.2, C15.2, C16.2, C17.2, C18.2, C19.2, C20.2, C21.2, C22.2, C23.2, C24.2, C25.2, C26.2, C27.2, C28.2, CON1.6, CON1.G1, CON1.G2, CON1.G4, D1.C, D2.C, MNT1.1, MNT2.1, MNT3.1, MNT4.1, P1.2, P1.5, R4.2, R6.2, R8.2, R10.2, R13.2, SW1.2, U1.10, U1.20, U1.27, U1.37, U1.74, U1.99, U2.2, U3.2, U4.2, U5.A1, U5.A3, U5.A4, U5.E4, U5.G2, X1.2, X2.3, X2.5
HREF: U1.29, U5.C3
IRCUT_A: C29.1, P2.1, U1.38, U1.39, U1.40, U1.41
IRCUT_B: P2.2, R14.2, U1.42, U1.43, U1.44, U1.45
MICROSD_CK: CON1.5, U1.80
MICROSD_CMD: CON1.3, U1.83
MICROSD_D0: CON1.7, R9.8, U1.65
MICROSD_D1: CON1.8, R9.7, U1.66
MICROSD_D2: CON1.1, R9.5, U1.78
MICROSD_D3: CON1.2, R9.6, U1.79
MICROSD_DETECT: CON1.G3, U1.46
NRST: C2.1, U1.14, X2.10
unnamed: C1.1, U1.49
unnamed: C3.1, U1.73
unnamed: C21.1, U5.A5
unnamed: C22.1, U5.C5
unnamed: C29.2, R14.1
unnamed: D1.A, R1.2
unnamed: D2.A, R2.2
unnamed: R3.2, R4.1, U2.4
unnamed: R5.2, R6.1, U3.4
unnamed: R7.2, R8.1, U4.4
unnamed: U1.12, X1.1
unnamed: U1.13, X1.3
PIXCK: U1.31, U5.E3
PWDN: U1.71, U5.B6
PWR_EN: U1.77, U3.3, U4.3
REBOOT_LATCH: C28.1, R13.1, U1.94, U1.95
RESET: U1.70, U5.C6
SIO_C: R11.2, U1.47, U5.C2
SIO_D: R12.2, U1.48, U5.C1
STATUS0: R1.1, U1.35
STATUS1: R2.1, U1.36
STROBE: U1.51, U5.A6
SWDCLK: U1.76, X2.4
SWDIO: U1.72, X2.2
SWO: U1.89, X2.6
UART_RX: P1.3, U1.69
UART_TX: P1.4, U1.68
VSYNC: U1.93, U5.D2
XCLK: U1.67, U5.C4

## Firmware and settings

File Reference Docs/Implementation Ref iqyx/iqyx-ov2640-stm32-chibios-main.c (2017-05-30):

/**
 * The following implementation is only a proof-of-concept that a OV2640
 * (or any other similar camera) can be easily connected to a MCU even without
 * the right hardware interface. Most F4 indeed does have the DCMI interface for
 * interfacing with such cameras, it was used only because the F4discovery
 * board was handy.
 *
 * My spaghetti code is dedicated to the public domain and I really hope that
 * nobody will ever use it. Some foreign parts use different licensing.
 */

#include "ch.h"
#include "hal.h"
#include "chprintf.h"

/* Allow chibios to use 64K of CCM memory on the F4. */
MemoryHeap ccm_heap;

/**
 * The following part is borrowed from the linux ov2640 driver. Some of the
 * registers are named but still there are many without any documentation.
 * Another possible source is the ArduCam project but it is not documented
 * and there are long arrays of magic values only.
 */

/*
 * ov2640 Camera Driver
 *
 * Copyright (C) 2010 Alberto Panizzo <maramaopercheseimorto@gmail.com>
 *
 * Based on ov772x, ov9640 drivers and previous non merged implementations.
 *
 * Copyright 2005-2009 Freescale Semiconductor, Inc. All Rights Reserved.
 * Copyright (C) 2006, OmniVision
 *
 * This program is free software; you can redistribute it and/or modify
 * it under the terms of the GNU General Public License version 2 as
 * published by the Free Software Foundation.
 */

#define VAL_SET(x, mask, rshift, lshift)  \
		((((x) >> rshift) & mask) << lshift)
/*
 * DSP registers
 * register offset for BANK_SEL == BANK_SEL_DSP
 */
#define R_BYPASS    0x05 /* Bypass DSP */
#define   R_BYPASS_DSP_BYPAS    0x01 /* Bypass DSP, sensor out directly */
#define   R_BYPASS_USE_DSP      0x00 /* Use the internal DSP */
#define QS          0x44 /* Quantization Scale Factor */
#define CTRLI       0x50
#define   CTRLI_LP_DP           0x80
#define   CTRLI_ROUND           0x40
#define   CTRLI_V_DIV_SET(x)    VAL_SET(x, 0x3, 0, 3)
#define   CTRLI_H_DIV_SET(x)    VAL_SET(x, 0x3, 0, 0)
#define HSIZE       0x51 /* H_SIZE[7:0] (real/4) */
#define   HSIZE_SET(x)          VAL_SET(x, 0xFF, 2, 0)
#define VSIZE       0x52 /* V_SIZE[7:0] (real/4) */
#define   VSIZE_SET(x)          VAL_SET(x, 0xFF, 2, 0)
#define XOFFL       0x53 /* OFFSET_X[7:0] */
#define   XOFFL_SET(x)          VAL_SET(x, 0xFF, 0, 0)
#define YOFFL       0x54 /* OFFSET_Y[7:0] */
#define   YOFFL_SET(x)          VAL_SET(x, 0xFF, 0, 0)
#define VHYX        0x55 /* Offset and size completion */
#define   VHYX_VSIZE_SET(x)     VAL_SET(x, 0x1, (8+2), 7)
#define   VHYX_HSIZE_SET(x)     VAL_SET(x, 0x1, (8+2), 3)
#define   VHYX_YOFF_SET(x)      VAL_SET(x, 0x3, 8, 4)
#define   VHYX_XOFF_SET(x)      VAL_SET(x, 0x3, 8, 0)
#define DPRP        0x56
#define TEST        0x57 /* Horizontal size completion */
#define   TEST_HSIZE_SET(x)     VAL_SET(x, 0x1, (9+2), 7)
#define ZMOW        0x5A /* Zoom: Out Width  OUTW[7:0] (real/4) */
#define   ZMOW_OUTW_SET(x)      VAL_SET(x, 0xFF, 2, 0)
#define ZMOH        0x5B /* Zoom: Out Height OUTH[7:0] (real/4) */
#define   ZMOH_OUTH_SET(x)      VAL_SET(x, 0xFF, 2, 0)
#define ZMHH        0x5C /* Zoom: Speed and H&W completion */
#define   ZMHH_ZSPEED_SET(x)    VAL_SET(x, 0x0F, 0, 4)
#define   ZMHH_OUTH_SET(x)      VAL_SET(x, 0x1, (8+2), 2)
#define   ZMHH_OUTW_SET(x)      VAL_SET(x, 0x3, (8+2), 0)
#define BPADDR      0x7C /* SDE Indirect Register Access: Address */
#define BPDATA      0x7D /* SDE Indirect Register Access: Data */
#define CTRL2       0x86 /* DSP Module enable 2 */
#define   CTRL2_DCW_EN          0x20
#define   CTRL2_SDE_EN          0x10
#define   CTRL2_UV_ADJ_EN       0x08
#define   CTRL2_UV_AVG_EN       0x04
#define   CTRL2_CMX_EN          0x01
#define CTRL3       0x87 /* DSP Module enable 3 */
#define   CTRL3_BPC_EN          0x80
#define   CTRL3_WPC_EN          0x40
#define SIZEL       0x8C /* Image Size Completion */
#define   SIZEL_HSIZE8_11_SET(x) VAL_SET(x, 0x1, 11, 6)
#define   SIZEL_HSIZE8_SET(x)    VAL_SET(x, 0x7, 0, 3)
#define   SIZEL_VSIZE8_SET(x)    VAL_SET(x, 0x7, 0, 0)
#define HSIZE8      0xC0 /* Image Horizontal Size HSIZE[10:3] */
#define   HSIZE8_SET(x)         VAL_SET(x, 0xFF, 3, 0)
#define VSIZE8      0xC1 /* Image Vertical Size VSIZE[10:3] */
#define   VSIZE8_SET(x)         VAL_SET(x, 0xFF, 3, 0)
#define CTRL0       0xC2 /* DSP Module enable 0 */
#define   CTRL0_AEC_EN       0x80
#define   CTRL0_AEC_SEL      0x40
#define   CTRL0_STAT_SEL     0x20
#define   CTRL0_VFIRST       0x10
#define   CTRL0_YUV422       0x08
#define   CTRL0_YUV_EN       0x04
#define   CTRL0_RGB_EN       0x02
#define   CTRL0_RAW_EN       0x01
#define CTRL1       0xC3 /* DSP Module enable 1 */
#define   CTRL1_CIP          0x80
#define   CTRL1_DMY          0x40
#define   CTRL1_RAW_GMA      0x20
#define   CTRL1_DG           0x10
#define   CTRL1_AWB          0x08
#define   CTRL1_AWB_GAIN     0x04
#define   CTRL1_LENC         0x02
#define   CTRL1_PRE          0x01
#define R_DVP_SP    0xD3 /* DVP output speed control */
#define   R_DVP_SP_AUTO_MODE 0x80
#define   R_DVP_SP_DVP_MASK  0x3F /* DVP PCLK = sysclk (48)/[6:0] (YUV0);
				   *          = sysclk (48)/(2*[6:0]) (RAW);*/
#define IMAGE_MODE  0xDA /* Image Output Format Select */
#define   IMAGE_MODE_Y8_DVP_EN   0x40
#define   IMAGE_MODE_JPEG_EN     0x10
#define   IMAGE_MODE_YUV422      0x00
#define   IMAGE_MODE_RAW10       0x04 /* (DVP) */
#define   IMAGE_MODE_RGB565      0x08
#define   IMAGE_MODE_HREF_VSYNC  0x02 /* HREF timing select in DVP JPEG output
				       * mode (0 for HREF is same as sensor) */
#define   IMAGE_MODE_LBYTE_FIRST 0x01 /* Byte swap enable for DVP
				       *    1: Low byte first UYVY (C2[4] =0)
				       *        VYUY (C2[4] =1)
				       *    0: High byte first YUYV (C2[4]=0)
				       *        YVYU (C2[4] = 1) */
#define RESET       0xE0 /* Reset */
#define   RESET_MICROC       0x40
#define   RESET_SCCB         0x20
#define   RESET_JPEG         0x10
#define   RESET_DVP          0x04
#define   RESET_IPU          0x02
#define   RESET_CIF          0x01
#define REGED       0xED /* Register ED */
#define   REGED_CLK_OUT_DIS  0x10
#define MS_SP       0xF0 /* SCCB Master Speed */
#define SS_ID       0xF7 /* SCCB Slave ID */
#define SS_CTRL     0xF8 /* SCCB Slave Control */
#define   SS_CTRL_ADD_AUTO_INC  0x20
#define   SS_CTRL_EN            0x08
#define   SS_CTRL_DELAY_CLK     0x04
#define   SS_CTRL_ACC_EN        0x02
#define   SS_CTRL_SEN_PASS_THR  0x01
#define MC_BIST     0xF9 /* Microcontroller misc register */
#define   MC_BIST_RESET           0x80 /* Microcontroller Reset */
#define   MC_BIST_BOOT_ROM_SEL    0x40
#define   MC_BIST_12KB_SEL        0x20
#define   MC_BIST_12KB_MASK       0x30
#define   MC_BIST_512KB_SEL       0x08
#define   MC_BIST_512KB_MASK      0x0C
#define   MC_BIST_BUSY_BIT_R      0x02
#define   MC_BIST_MC_RES_ONE_SH_W 0x02
#define   MC_BIST_LAUNCH          0x01
#define BANK_SEL    0xFF /* Register Bank Select */
#define   BANK_SEL_DSP     0x00
#define   BANK_SEL_SENS    0x01

/*
 * Sensor registers
 * register offset for BANK_SEL == BANK_SEL_SENS
 */
#define GAIN        0x00 /* AGC - Gain control gain setting */
#define COM1        0x03 /* Common control 1 */
#define   COM1_1_DUMMY_FR          0x40
#define   COM1_3_DUMMY_FR          0x80
#define   COM1_7_DUMMY_FR          0xC0
#define   COM1_VWIN_LSB_UXGA       0x0F
#define   COM1_VWIN_LSB_SVGA       0x0A
#define   COM1_VWIN_LSB_CIF        0x06
#define REG04       0x04 /* Register 04 */
#define   REG04_DEF             0x20 /* Always set */
#define   REG04_HFLIP_IMG       0x80 /* Horizontal mirror image ON/OFF */
#define   REG04_VFLIP_IMG       0x40 /* Vertical flip image ON/OFF */
#define   REG04_VREF_EN         0x10
#define   REG04_HREF_EN         0x08
#define   REG04_AEC_SET(x)      VAL_SET(x, 0x3, 0, 0)
#define REG08       0x08 /* Frame Exposure One-pin Control Pre-charge Row Num */
#define COM2        0x09 /* Common control 2 */
#define   COM2_SOFT_SLEEP_MODE  0x10 /* Soft sleep mode */
				     /* Output drive capability */
#define   COM2_OCAP_Nx_SET(N)   (((N) - 1) & 0x03) /* N = [1x .. 4x] */
#define PID         0x0A /* Product ID Number MSB */
#define VER         0x0B /* Product ID Number LSB */
#define COM3        0x0C /* Common control 3 */
#define   COM3_BAND_50H        0x04 /* 0 For Banding at 60H */
#define   COM3_BAND_AUTO       0x02 /* Auto Banding */
#define   COM3_SING_FR_SNAPSH  0x01 /* 0 For enable live video output after the
				     * snapshot sequence*/
#define AEC         0x10 /* AEC[9:2] Exposure Value */
#define CLKRC       0x11 /* Internal clock */
#define   CLKRC_EN             0x80
#define   CLKRC_DIV_SET(x)     (((x) - 1) & 0x1F) /* CLK = XVCLK/(x) */
#define COM7        0x12 /* Common control 7 */
#define   COM7_SRST            0x80 /* Initiates system reset. All registers are
				     * set to factory default values after which
				     * the chip resumes normal operation */
#define   COM7_RES_UXGA        0x00 /* Resolution selectors for UXGA */
#define   COM7_RES_SVGA        0x40 /* SVGA */
#define   COM7_RES_CIF         0x20 /* CIF */
#define   COM7_ZOOM_EN         0x04 /* Enable Zoom mode */
#define   COM7_COLOR_BAR_TEST  0x02 /* Enable Color Bar Test Pattern */
#define COM8        0x13 /* Common control 8 */
#define   COM8_DEF             0xC0 /* Banding filter ON/OFF */
#define   COM8_BNDF_EN         0x20 /* Banding filter ON/OFF */
#define   COM8_AGC_EN          0x04 /* AGC Auto/Manual control selection */
#define   COM8_AEC_EN          0x01 /* Auto/Manual Exposure control */
#define COM9        0x14 /* Common control 9
			  * Automatic gain ceiling - maximum AGC value [7:5]*/
#define   COM9_AGC_GAIN_2x     0x00 /* 000 :   2x */
#define   COM9_AGC_GAIN_4x     0x20 /* 001 :   4x */
#define   COM9_AGC_GAIN_8x     0x40 /* 010 :   8x */
#define   COM9_AGC_GAIN_16x    0x60 /* 011 :  16x */
#define   COM9_AGC_GAIN_32x    0x80 /* 100 :  32x */
#define   COM9_AGC_GAIN_64x    0xA0 /* 101 :  64x */
#define   COM9_AGC_GAIN_128x   0xC0 /* 110 : 128x */
#define COM10       0x15 /* Common control 10 */
#define   COM10_PCLK_HREF      0x20 /* PCLK output qualified by HREF */
#define   COM10_PCLK_RISE      0x10 /* Data is updated at the rising edge of
				     * PCLK (user can latch data at the next
				     * falling edge of PCLK).
				     * 0 otherwise. */
#define   COM10_HREF_INV       0x08 /* Invert HREF polarity:
				     * HREF negative for valid data*/
#define   COM10_VSINC_INV      0x02 /* Invert VSYNC polarity */
#define HSTART      0x17 /* Horizontal Window start MSB 8 bit */
#define HEND        0x18 /* Horizontal Window end MSB 8 bit */
#define VSTART      0x19 /* Vertical Window start MSB 8 bit */
#define VEND        0x1A /* Vertical Window end MSB 8 bit */
#define MIDH        0x1C /* Manufacturer ID byte - high */
#define MIDL        0x1D /* Manufacturer ID byte - low  */
#define AEW         0x24 /* AGC/AEC - Stable operating region (upper limit) */
#define AEB         0x25 /* AGC/AEC - Stable operating region (lower limit) */
#define VV          0x26 /* AGC/AEC Fast mode operating region */
#define   VV_HIGH_TH_SET(x)      VAL_SET(x, 0xF, 0, 4)
#define   VV_LOW_TH_SET(x)       VAL_SET(x, 0xF, 0, 0)
#define REG2A       0x2A /* Dummy pixel insert MSB */
#define FRARL       0x2B /* Dummy pixel insert LSB */
#define ADDVFL      0x2D /* LSB of insert dummy lines in Vertical direction */
#define ADDVFH      0x2E /* MSB of insert dummy lines in Vertical direction */
#define YAVG        0x2F /* Y/G Channel Average value */
#define REG32       0x32 /* Common Control 32 */
#define   REG32_PCLK_DIV_2    0x80 /* PCLK freq divided by 2 */
#define   REG32_PCLK_DIV_4    0xC0 /* PCLK freq divided by 4 */
#define ARCOM2      0x34 /* Zoom: Horizontal start point */
#define REG45       0x45 /* Register 45 */
#define FLL         0x46 /* Frame Length Adjustment LSBs */
#define FLH         0x47 /* Frame Length Adjustment MSBs */
#define COM19       0x48 /* Zoom: Vertical start point */
#define ZOOMS       0x49 /* Zoom: Vertical start point */
#define COM22       0x4B /* Flash light control */
#define COM25       0x4E /* For Banding operations */
#define BD50        0x4F /* 50Hz Banding AEC 8 LSBs */
#define BD60        0x50 /* 60Hz Banding AEC 8 LSBs */
#define REG5D       0x5D /* AVGsel[7:0],   16-zone average weight option */
#define REG5E       0x5E /* AVGsel[15:8],  16-zone average weight option */
#define REG5F       0x5F /* AVGsel[23:16], 16-zone average weight option */
#define REG60       0x60 /* AVGsel[31:24], 16-zone average weight option */
#define HISTO_LOW   0x61 /* Histogram Algorithm Low Level */
#define HISTO_HIGH  0x62 /* Histogram Algorithm High Level */

#define MANUFACTURER_ID	0x7FA2
#define PID_OV2640	0x2642
#define VERSION(pid, ver) ((pid << 8) | (ver & 0xFF))

struct regval_list {
	u8 reg_num;
	u8 value;
};

/* Supported resolutions */
enum ov2640_width {
	W_QCIF	= 176,
	W_QVGA	= 320,
	W_CIF	= 352,
	W_VGA	= 640,
	W_SVGA	= 800,
	W_XGA	= 1024,
	W_SXGA	= 1280,
	W_UXGA	= 1600,
};

enum ov2640_height {
	H_QCIF	= 144,
	H_QVGA	= 240,
	H_CIF	= 288,
	H_VGA	= 480,
	H_SVGA	= 600,
	H_XGA	= 768,
	H_SXGA	= 1024,
	H_UXGA	= 1200,
};

struct ov2640_win_size {
	char				*name;
	enum ov2640_width		width;
	enum ov2640_height		height;
	const struct regval_list	*regs;
};


/*
 * Registers settings. Most of them are undocumented. Some documentation is
 * is available in the OV2640 datasheet, the OV2640 hardware app notes and
 * the OV2640 software app notes documents.
 */

#define ENDMARKER { 0xff, 0xff }

static const struct regval_list ov2640_init_regs[] = {
	{ BANK_SEL, BANK_SEL_DSP },
	{ 0x2c,   0xff },
	{ 0x2e,   0xdf },
	{ BANK_SEL, BANK_SEL_SENS },
	{ 0x3c,   0x32 },
	{ CLKRC, CLKRC_DIV_SET(20) },
	{ COM2, COM2_OCAP_Nx_SET(3) },
	{ REG04, REG04_DEF | REG04_HREF_EN },
	{ COM8,  COM8_DEF | COM8_AGC_EN | COM8_AEC_EN },
	//~ { AEC,    0x00 },
	{ COM9, COM9_AGC_GAIN_8x | 0x08},
	{ 0x2c,   0x0c },
	{ 0x33,   0x78 },
	{ 0x3a,   0x33 },
	{ 0x3b,   0xfb },
	{ 0x3e,   0x00 },
	{ 0x43,   0x11 },
	{ 0x16,   0x10 },
	{ 0x39,   0x02 },
	{ 0x35,   0x88 },
	{ 0x22,   0x0a },
	{ 0x37,   0x40 },
	{ 0x23,   0x00 },
	{ ARCOM2, 0xa0 },
	{ 0x06,   0x02 },
	{ 0x06,   0x88 },
	{ 0x07,   0xc0 },
	{ 0x0d,   0xb7 },
	{ 0x0e,   0x01 },
	{ 0x4c,   0x00 },
	{ 0x4a,   0x81 },
	{ 0x21,   0x99 },
	{ AEW,    0x40 },
	{ AEB,    0x38 },
	{ VV,     VV_HIGH_TH_SET(0x08) | VV_LOW_TH_SET(0x02) },
	{ 0x5c,   0x00 },
	{ 0x63,   0x00 },
	{ FLL,    0x22 },
	{ COM3,   0x38 | COM3_BAND_AUTO },
	{ REG5D,  0x55 },
	{ REG5E,  0x7d },
	{ REG5F,  0x7d },
	{ REG60,  0x55 },
	{ HISTO_LOW,   0x70 },
	{ HISTO_HIGH,  0x80 },
	{ 0x7c,   0x05 },
	{ 0x20,   0x80 },
	{ 0x28,   0x30 },
	{ 0x6c,   0x00 },
	{ 0x6d,   0x80 },
	{ 0x6e,   0x00 },
	{ 0x70,   0x02 },
	{ 0x71,   0x94 },
	{ 0x73,   0xc1 },
	{ 0x3d,   0x34 },
	{ COM7, COM7_RES_UXGA | COM7_ZOOM_EN },
	{ 0x5a,   0x57 },
	{ BD50,   0xbb },
	{ BD60,   0x9c },
	{ BANK_SEL, BANK_SEL_DSP },
	{ 0xe5,   0x7f },
	{ MC_BIST, MC_BIST_RESET | MC_BIST_BOOT_ROM_SEL },
	{ 0x41,   0x24 },
	{ RESET, RESET_JPEG | RESET_DVP },
	{ 0x76,   0xff },
	{ 0x33,   0xa0 },
	{ 0x42,   0x20 },
	{ 0x43,   0x18 },
	{ 0x4c,   0x00 },
	{ CTRL3, CTRL3_BPC_EN | CTRL3_WPC_EN | 0x10 },
	{ 0x88,   0x3f },
	{ 0xd7,   0x03 },
	{ 0xd9,   0x10 },
	{ R_DVP_SP , R_DVP_SP_AUTO_MODE | 0x2 },
	{ 0xc8,   0x08 },
	{ 0xc9,   0x80 },
	{ BPADDR, 0x00 },
	{ BPDATA, 0x00 },
	{ BPADDR, 0x03 },
	{ BPDATA, 0x48 },
	{ BPDATA, 0x48 },
	{ BPADDR, 0x08 },
	{ BPDATA, 0x20 },
	{ BPDATA, 0x10 },
	{ BPDATA, 0x0e },
	{ 0x90,   0x00 },
	{ 0x91,   0x0e },
	{ 0x91,   0x1a },
	{ 0x91,   0x31 },
	{ 0x91,   0x5a },
	{ 0x91,   0x69 },
	{ 0x91,   0x75 },
	{ 0x91,   0x7e },
	{ 0x91,   0x88 },
	{ 0x91,   0x8f },
	{ 0x91,   0x96 },
	{ 0x91,   0xa3 },
	{ 0x91,   0xaf },
	{ 0x91,   0xc4 },
	{ 0x91,   0xd7 },
	{ 0x91,   0xe8 },
	{ 0x91,   0x20 },
	{ 0x92,   0x00 },
	{ 0x93,   0x06 },
	{ 0x93,   0xe3 },
	{ 0x93,   0x03 },
	{ 0x93,   0x03 },
	{ 0x93,   0x00 },
	{ 0x93,   0x02 },
	{ 0x93,   0x00 },
	{ 0x93,   0x00 },
	{ 0x93,   0x00 },
	{ 0x93,   0x00 },
	{ 0x93,   0x00 },
	{ 0x93,   0x00 },
	{ 0x93,   0x00 },
	{ 0x96,   0x00 },
	{ 0x97,   0x08 },
	{ 0x97,   0x19 },
	{ 0x97,   0x02 },
	{ 0x97,   0x0c },
	{ 0x97,   0x24 },
	{ 0x97,   0x30 },
	{ 0x97,   0x28 },
	{ 0x97,   0x26 },
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
	{ 0xc7,   0x10 }, /* white balance */
	{ 0xb6,   0x66 },
	{ 0xb8,   0xA5 },
	{ 0xb7,   0x64 },
	{ 0xb9,   0x7C },
	{ 0xb3,   0xaf },
	{ 0xb4,   0x97 },
	{ 0xb5,   0xFF },
	{ 0xb0,   0xC5 },
	{ 0xb1,   0x94 },
	{ 0xb2,   0x0f },
	{ 0xc4,   0x5c },
	{ 0xa6,   0x00 },
	{ 0xa7,   0x20 },
	{ 0xa7,   0xd8 },
	{ 0xa7,   0x1b },
	{ 0xa7,   0x31 },
	{ 0xa7,   0x00 },
	{ 0xa7,   0x18 },
	{ 0xa7,   0x20 },
	{ 0xa7,   0xd8 },
	{ 0xa7,   0x19 },
	{ 0xa7,   0x31 },
	{ 0xa7,   0x00 },
	{ 0xa7,   0x18 },
	{ 0xa7,   0x20 },
	{ 0xa7,   0xd8 },
	{ 0xa7,   0x19 },
	{ 0xa7,   0x31 },
	{ 0xa7,   0x00 },
	{ 0xa7,   0x18 },
	{ 0x7f,   0x00 },
	{ 0xe5,   0x1f },
	{ 0xe1,   0x77 },
	{ 0xdd,   0x7f },
	{ CTRL0,  CTRL0_YUV422 | CTRL0_YUV_EN },
	ENDMARKER,
};

/*
 * Register settings for window size
 * The preamble, setup the internal DSP to input an UXGA (1600x1200) image.
 * Then the different zooming configurations will setup the output image size.
 */
static const struct regval_list ov2640_size_change_preamble_regs[] = {
	{ BANK_SEL, BANK_SEL_DSP },
	{ RESET, RESET_DVP },
	{ HSIZE8, HSIZE8_SET(W_UXGA) },
	{ VSIZE8, VSIZE8_SET(H_UXGA) },
	{ CTRL2, CTRL2_DCW_EN | CTRL2_SDE_EN |
		 CTRL2_UV_AVG_EN | CTRL2_CMX_EN | CTRL2_UV_ADJ_EN },
	{ HSIZE, HSIZE_SET(W_UXGA) },
	{ VSIZE, VSIZE_SET(H_UXGA) },
	{ XOFFL, XOFFL_SET(0) },
	{ YOFFL, YOFFL_SET(0) },
	{ VHYX, VHYX_HSIZE_SET(W_UXGA) | VHYX_VSIZE_SET(H_UXGA) |
		VHYX_XOFF_SET(0) | VHYX_YOFF_SET(0)},
	{ TEST, TEST_HSIZE_SET(W_UXGA) },
	ENDMARKER,
};

#define PER_SIZE_REG_SEQ(x, y, v_div, h_div, pclk_div)	\
	{ CTRLI, CTRLI_LP_DP | CTRLI_V_DIV_SET(v_div) |	\
		 CTRLI_H_DIV_SET(h_div)},		\
	{ ZMOW, ZMOW_OUTW_SET(x) },			\
	{ ZMOH, ZMOH_OUTH_SET(y) },			\
	{ ZMHH, ZMHH_OUTW_SET(x) | ZMHH_OUTH_SET(y) },	\
	{ R_DVP_SP, pclk_div },				\
	{ RESET, 0x00}

static const struct regval_list ov2640_qcif_regs[] = {
	PER_SIZE_REG_SEQ(W_QCIF, H_QCIF, 3, 3, 4),
	ENDMARKER,
};

static const struct regval_list ov2640_qvga_regs[] = {
	PER_SIZE_REG_SEQ(W_QVGA, H_QVGA, 2, 2, 4),
	ENDMARKER,
};

static const struct regval_list ov2640_cif_regs[] = {
	PER_SIZE_REG_SEQ(W_CIF, H_CIF, 2, 2, 8),
	ENDMARKER,
};

static const struct regval_list ov2640_vga_regs[] = {
	PER_SIZE_REG_SEQ(W_VGA, H_VGA, 0, 0, 2),
	ENDMARKER,
};

static const struct regval_list ov2640_svga_regs[] = {
	PER_SIZE_REG_SEQ(W_SVGA, H_SVGA, 1, 1, 2),
	ENDMARKER,
};

static const struct regval_list ov2640_xga_regs[] = {
	PER_SIZE_REG_SEQ(W_XGA, H_XGA, 0, 0, 2),
	{ CTRLI,    0x00},
	ENDMARKER,
};

static const struct regval_list ov2640_sxga_regs[] = {
	PER_SIZE_REG_SEQ(W_SXGA, H_SXGA, 0, 0, 2),
	{ CTRLI,    0x00},
	{ R_DVP_SP, 2 | R_DVP_SP_AUTO_MODE },
	ENDMARKER,
};

static const struct regval_list ov2640_uxga_regs[] = {
	PER_SIZE_REG_SEQ(W_UXGA, H_UXGA, 0, 0, 0),
	{ CTRLI,    0x00},
	{ R_DVP_SP, 0 | R_DVP_SP_AUTO_MODE },
	ENDMARKER,
};

#define OV2640_SIZE(n, w, h, r) \
	{.name = n, .width = w , .height = h, .regs = r }

static const struct ov2640_win_size ov2640_supported_win_sizes[] = {
	OV2640_SIZE("QCIF", W_QCIF, H_QCIF, ov2640_qcif_regs),
	OV2640_SIZE("QVGA", W_QVGA, H_QVGA, ov2640_qvga_regs),
	OV2640_SIZE("CIF", W_CIF, H_CIF, ov2640_cif_regs),
	OV2640_SIZE("VGA", W_VGA, H_VGA, ov2640_vga_regs),
	OV2640_SIZE("SVGA", W_SVGA, H_SVGA, ov2640_svga_regs),
	OV2640_SIZE("XGA", W_XGA, H_XGA, ov2640_xga_regs),
	OV2640_SIZE("SXGA", W_SXGA, H_SXGA, ov2640_sxga_regs),
	OV2640_SIZE("UXGA", W_UXGA, H_UXGA, ov2640_uxga_regs),
};

/*
 * Register settings for pixel formats
 */
static const struct regval_list ov2640_format_change_preamble_regs[] = {
	{ BANK_SEL, BANK_SEL_DSP },
	{ R_BYPASS, R_BYPASS_USE_DSP },
	ENDMARKER,
};

static const struct regval_list ov2640_yuyv_regs[] = {
	{ IMAGE_MODE, IMAGE_MODE_YUV422 },
	{ 0xd7, 0x03 },
	{ 0x33, 0xa0 },
	{ 0xe5, 0x1f },
	{ 0xe1, 0x67 },
	{ RESET,  0x00 },
	{ R_BYPASS, R_BYPASS_USE_DSP },
	ENDMARKER,
};

static const struct regval_list ov2640_uyvy_regs[] = {
	{ IMAGE_MODE, IMAGE_MODE_LBYTE_FIRST | IMAGE_MODE_YUV422 },
	{ 0xd7, 0x01 },
	{ 0x33, 0xa0 },
	{ 0xe1, 0x67 },
	{ RESET,  0x00 },
	{ R_BYPASS, R_BYPASS_USE_DSP },
	ENDMARKER,
};

static const struct regval_list ov2640_rgb565_be_regs[] = {
	{ IMAGE_MODE, IMAGE_MODE_RGB565 },
	{ 0xd7, 0x03 },
	{ RESET,  0x00 },
	{ R_BYPASS, R_BYPASS_USE_DSP },
	ENDMARKER,
};

static const struct regval_list ov2640_rgb565_le_regs[] = {
	{ IMAGE_MODE, IMAGE_MODE_LBYTE_FIRST | IMAGE_MODE_RGB565 },
	{ 0xd7, 0x03 },
	{ RESET,  0x00 },
	{ R_BYPASS, R_BYPASS_USE_DSP },
	ENDMARKER,
};

static const struct regval_list ov2640_jpeg_regs[] = {
	{ BANK_SEL, BANK_SEL_DSP },
	{ 0xe0, 0x14 },
	{ 0xe1, 0x77 },
	{ 0xe5, 0x1f },
	{ 0xd7, 0x03 },
	{ IMAGE_MODE, IMAGE_MODE_JPEG_EN },
	{ 0xe0, 0x00 },
	{ BANK_SEL, BANK_SEL_SENS },
	{ 0x04, 0x08 },
	//~ { RESET,  RESET_DVP | RESET_JPEG },
	ENDMARKER,
};

/**
 * ChibiOS HAL configuration part.
 */
static const I2CConfig i2cfg1 = {
	OPMODE_I2C,
	100000,
	FAST_DUTY_CYCLE_2,
};

static const PWMConfig pwmcfg3 = {
	20000000,
	2,
	NULL,
	{
		{PWM_OUTPUT_ACTIVE_HIGH, NULL},
		{PWM_OUTPUT_DISABLED, NULL},
		{PWM_OUTPUT_DISABLED, NULL},
		{PWM_OUTPUT_DISABLED, NULL}
	},
	0,
	0
};
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
int main(void) {

	halInit();
	chSysInit();
	chHeapInit(&ccm_heap, (void *)0x10000000, 0x10000);

	/* leds */
	palSetPadMode(GPIOD, 12, PAL_MODE_OUTPUT_PUSHPULL);
	palSetPadMode(GPIOD, 13, PAL_MODE_OUTPUT_PUSHPULL);
	palSetPadMode(GPIOD, 14, PAL_MODE_OUTPUT_PUSHPULL);
	palSetPadMode(GPIOD, 15, PAL_MODE_OUTPUT_PUSHPULL);

	palClearPad(GPIOD, 12);
	palClearPad(GPIOD, 13);
	palClearPad(GPIOD, 14);
	palClearPad(GPIOD, 15);


	chThdCreateFromHeap(NULL, 4000, NORMALPRIO, Thread1, NULL);

	while (1) {
		chThdSleepMilliseconds(500);
	}
}

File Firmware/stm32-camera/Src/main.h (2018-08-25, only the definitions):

#define AMBIENT_LIGHT_Pin GPIO_PIN_0
#define AMBIENT_LIGHT_GPIO_Port GPIOC
#define FLASH_OUTPUT_Pin GPIO_PIN_5
#define FLASH_OUTPUT_GPIO_Port GPIOA
#define STATUS0_Pin GPIO_PIN_0
#define STATUS0_GPIO_Port GPIOB
#define STATUS1_Pin GPIO_PIN_1
#define STATUS1_GPIO_Port GPIOB
#define SDIO_DETECT_Pin GPIO_PIN_15
#define SDIO_DETECT_GPIO_Port GPIOE
#define STROBE_Pin GPIO_PIN_14
#define STROBE_GPIO_Port GPIOB
#define EXPST_Pin GPIO_PIN_15
#define EXPST_GPIO_Port GPIOB
#define FREX_Pin GPIO_PIN_8
#define FREX_GPIO_Port GPIOD
#define XCLK_Pin GPIO_PIN_8
#define XCLK_GPIO_Port GPIOA
#define RES_Pin GPIO_PIN_11
#define RES_GPIO_Port GPIOA
#define PWDN_Pin GPIO_PIN_12
#define PWDN_GPIO_Port GPIOA
#define REG_EN_Pin GPIO_PIN_15
#define REG_EN_GPIO_Port GPIOA
#define EXP_1_Pin GPIO_PIN_0
#define EXP_1_GPIO_Port GPIOD
#define EXP_0_Pin GPIO_PIN_1
#define EXP_0_GPIO_Port GPIOD
#define BUTTON_0_Pin GPIO_PIN_3
#define BUTTON_0_GPIO_Port GPIOD
#define REBOOT_LATCH_Pin GPIO_PIN_8
#define REBOOT_LATCH_GPIO_Port GPIOB

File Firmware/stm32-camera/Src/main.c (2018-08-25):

/**
  ******************************************************************************
  * File Name          : main.c
  * Description        : Main program body
  ******************************************************************************
  * This notice applies to any and all portions of this file
  * that are not between comment pairs USER CODE BEGIN and
  * USER CODE END. Other portions of this file, whether 
  * inserted by the user or by software development tools
  * are owned by their respective copyright owners.
  *
  * Copyright (c) 2017 STMicroelectronics International N.V. 
  * All rights reserved.
  *
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
  ******************************************************************************
  */
/* Includes ------------------------------------------------------------------*/
#include "main.h"
#include "stm32f4xx_hal.h"
#include "dma.h"
#include "sdio.h"

/* USER CODE BEGIN Includes */
#include "global.h"
#include "qassert.h"
#include "app_tasks.h"
#include "app_hardware.h"
#include "status.h"
#include "hal_gpio.h"
#include "hal_watchdog.h"
#include "hal_system_speed.h"
#include "filesystem.h"

/* Assert printout requirements */
#include <string.h>
#include <stdarg.h>
#include "hal_uart.h"
#include "hal_delay.h"

/* USER CODE END Includes */


/* USER CODE BEGIN PV */

#if defined(NASSERT) || defined(NDEBUG)
	#if defined( USE_FULL_ASSERT ) || (USE_FULL_ASSERT > 0)
		#error "You are building a RELEASE version while STM HAL library ASSERTs are still enabled!"
	#endif
#endif


/* USER CODE END PV */

void SystemClock_Config(void);

/* USER CODE BEGIN PFP */

/* USER CODE END PFP */

int main(void)
{

  /* MCU Configuration----------------------------------------------------------*/

  /* Reset of all peripherals, Initializes the Flash interface and the Systick. */
  HAL_Init();

  /* Configure the system clock */
  SystemClock_Config();

  /* USER CODE BEGIN SysInit */
  app_hardware_init();
  /* USER CODE END SysInit */

  /* Initialize all configured peripherals */
  MX_DMA_Init();
  filesystem_init();
  MX_SDIO_SD_Init();

  /* USER CODE BEGIN 2 */
  app_tasks_init();
  PERMIT();
  /* USER CODE END 2 */

  /* Infinite loop */
  /* USER CODE BEGIN WHILE */
  while (1)
  {
  /* USER CODE END WHILE */

  /* USER CODE BEGIN 3 */
      /* Run a dispatch cycle for the application event handlers */
      if( !app_tasks_run() )
      {
          status_red(false);
          hal_watchdog_refresh();
          hal_system_speed_sleep();
      }
      hal_watchdog_refresh();
      status_red(true);
  }
  /* USER CODE END 3 */

}

/** System Clock Configuration
*/
void SystemClock_Config(void)
{

  RCC_OscInitTypeDef RCC_OscInitStruct;
  RCC_ClkInitTypeDef RCC_ClkInitStruct;

    /**Configure the main internal regulator output voltage 
    */
  __HAL_RCC_PWR_CLK_ENABLE();

  __HAL_PWR_VOLTAGESCALING_CONFIG(PWR_REGULATOR_VOLTAGE_SCALE1);

    /**Initializes the CPU, AHB and APB busses clocks 
    */
  RCC_OscInitStruct.OscillatorType = RCC_OSCILLATORTYPE_HSI|RCC_OSCILLATORTYPE_LSI
                              |RCC_OSCILLATORTYPE_HSE;
  RCC_OscInitStruct.HSEState = RCC_HSE_ON;
  RCC_OscInitStruct.HSIState = RCC_HSI_ON;
  RCC_OscInitStruct.HSICalibrationValue = 16;
  RCC_OscInitStruct.LSIState = RCC_LSI_ON;
  RCC_OscInitStruct.PLL.PLLState = RCC_PLL_ON;
  RCC_OscInitStruct.PLL.PLLSource = RCC_PLLSOURCE_HSE;
  RCC_OscInitStruct.PLL.PLLM = 4;
  RCC_OscInitStruct.PLL.PLLN = 180;
  RCC_OscInitStruct.PLL.PLLP = RCC_PLLP_DIV2;
  RCC_OscInitStruct.PLL.PLLQ = 8;
  if (HAL_RCC_OscConfig(&RCC_OscInitStruct) != HAL_OK)
  {
    _Error_Handler(__FILE__, __LINE__);
  }

    /**Activate the Over-Drive mode 
    */
  if (HAL_PWREx_EnableOverDrive() != HAL_OK)
  {
    _Error_Handler(__FILE__, __LINE__);
  }

    /**Initializes the CPU, AHB and APB busses clocks 
    */
  RCC_ClkInitStruct.ClockType = RCC_CLOCKTYPE_HCLK|RCC_CLOCKTYPE_SYSCLK
                              |RCC_CLOCKTYPE_PCLK1|RCC_CLOCKTYPE_PCLK2;
  RCC_ClkInitStruct.SYSCLKSource = RCC_SYSCLKSOURCE_PLLCLK;
  RCC_ClkInitStruct.AHBCLKDivider = RCC_SYSCLK_DIV1;
  RCC_ClkInitStruct.APB1CLKDivider = RCC_HCLK_DIV4;
  RCC_ClkInitStruct.APB2CLKDivider = RCC_HCLK_DIV2;

  if (HAL_RCC_ClockConfig(&RCC_ClkInitStruct, FLASH_LATENCY_5) != HAL_OK)
  {
    _Error_Handler(__FILE__, __LINE__);
  }

    /**Configure the Systick interrupt time 
    */
  HAL_SYSTICK_Config(HAL_RCC_GetHCLKFreq()/1000);

    /**Configure the Systick 
    */
  HAL_SYSTICK_CLKSourceConfig(SYSTICK_CLKSOURCE_HCLK);

  /* SysTick_IRQn interrupt configuration */
  HAL_NVIC_SetPriority(SysTick_IRQn, 0, 0);
}

/* USER CODE BEGIN 4 */
void onAssert__( const char * file,
                 unsigned     line,
                 const char * fmt,
                 ... )
{
    va_list args;
    char message[32];
    int len;
    memset( message, 0, sizeof(message) );

    /* Format the printf part */
    if( fmt && ( strlen( fmt ) > 0 ) )
    {
        va_start( args, fmt );
        len = vsnprintf( message, sizeof(message), fmt, args );
        va_end( args );
    }

	/* Show assert in terminal  */
    hal_uart_printf_direct( HAL_UART_PORT_MAIN, "ASSERT: %s, line %d (%s)\r\n\r\n", file, line, message );

    /* Blinking lights while we wait for the watch dog to bite */
    status_red( true );
    status_green( false );
    while (1)
    {
        hal_delay_ms( 100 );
        status_red_toggle();
        status_green_toggle();
    }
}
/* USER CODE END 4 */
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


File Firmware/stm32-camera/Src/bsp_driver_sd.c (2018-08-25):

/**
 ******************************************************************************
  * @file    bsp_driver_sd.c for F4 (based on stm324x9i_eval_sd.c)
  * @brief   This file includes a generic uSD card driver.
  ******************************************************************************
  * This notice applies to any and all portions of this file
  * that are not between comment pairs USER CODE BEGIN and
  * USER CODE END. Other portions of this file, whether 
  * inserted by the user or by software development tools
  * are owned by their respective copyright owners.
  *
  * Copyright (c) 2017 STMicroelectronics International N.V. 
  * All rights reserved.
  *
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
  ******************************************************************************
  */
#define BUS_4BITS 1

#ifdef OLD_API
/* kept to avoid issue when migrating old projects. */
#else
/* USER CODE BEGIN FirstSection */
/* can be used to modify / undefine following code or add new definitions */
/* USER CODE END FirstSection */
/* Includes ------------------------------------------------------------------*/
#include "bsp_driver_sd.h"

/* Extern variables ---------------------------------------------------------*/ 
  
extern SD_HandleTypeDef hsd;

/* USER CODE BEGIN BeforeInitSection */
/* can be used to modify / undefine following code or add code */
/* USER CODE END BeforeInitSection */
/**
  * @brief  Initializes the SD card device.
  * @retval SD status
  */
uint8_t BSP_SD_Init(void)
{
  uint8_t sd_state = MSD_OK;
  /* Check if the SD card is plugged in the slot */
  if (BSP_SD_IsDetected() != SD_PRESENT)
  {
    return MSD_ERROR;
  }
  /* HAL SD initialization */
  sd_state = HAL_SD_Init(&hsd);
#ifdef BUS_4BITS
  /* Configure SD Bus width */
  if (sd_state == MSD_OK)
  {
    /* Enable wide operation */
    if (HAL_SD_ConfigWideBusOperation(&hsd, SDIO_BUS_WIDE_4B) != HAL_OK)
    {
      sd_state = MSD_ERROR;
    }
  }
#endif
  return sd_state;
}
/* USER CODE BEGIN AfterInitSection */
/* can be used to modify previous code / undefine following code / add code */
/* USER CODE END AfterInitSection */

/**
  * @brief  Configures Interrupt mode for SD detection pin.
  * @retval Returns 0 in success otherwise 1. 
  */
uint8_t BSP_SD_ITConfig(void)
{  
  /* TBI: add user code here depending on the hardware configuration used */
  
  return (uint8_t)0;
}

/** @brief  SD detect IT treatment
  */
void BSP_SD_DetectIT(void)
{
  /* TBI: add user code here depending on the hardware configuration used */
}

/** @brief  SD detect IT detection callback
  */
__weak void BSP_SD_DetectCallback(void)
{
  /* NOTE: This function Should not be modified, when the callback is needed,
     the BSP_SD_DetectCallback could be implemented in the user file
  */ 
}

/* USER CODE BEGIN BeforeReadBlocksSection */
/* can be used to modify previous code / undefine following code / add code */
/* USER CODE END BeforeReadBlocksSection */
/**
  * @brief  Reads block(s) from a specified address in an SD card, in polling mode.
  * @param  pData: Pointer to the buffer that will contain the data to transmit
  * @param  ReadAddr: Address from where data is to be read  
  * @param  NumOfBlocks: Number of SD blocks to read 
  * @param  Timeout: Timeout for read operation
  * @retval SD status
  */
uint8_t BSP_SD_ReadBlocks(uint32_t *pData, uint32_t ReadAddr, uint32_t NumOfBlocks, uint32_t Timeout)
{
  uint8_t sd_state = MSD_OK;
  
  if (HAL_SD_ReadBlocks(&hsd, (uint8_t *)pData, ReadAddr, NumOfBlocks, Timeout) != HAL_OK)
  {
    sd_state = MSD_ERROR;
  }

  return sd_state;  
}
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

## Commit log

2017-05-30 Dump of reference material and notes
2017-06-19 Added M12 lens mount block SW part
    [M12 Lens Mount Basic Block.SLDPRT]
2017-06-19 Renamed MCAD to mechanical folder
    [M12 Lens Mount Basic Block.SLDPRT]
2017-06-19 Added KiCad project and sheets. Rough stubs
    [Camera.sch, Microcontroller.sch, Miscellaneous.sch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]
2017-06-19 Sensor pinout, net and global labels, lots of notes. Notes in readmes, creation of electronics specific notes file.
    [Camera.sch, Microcontroller.sch, Miscellaneous.sch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]
2017-06-19 Power labels, more global nets, text and formatting.
    [Camera.sch, Microcontroller.sch, Miscellaneous.sch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]
2017-06-20 Regulator stubs added
    [Camera.sch, Microcontroller.sch, Miscellaneous.sch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]
2017-06-20 Added SW model for IR swappable filter and lens mount
    [M12 Switchable IR Cut Filter Mount.SLDPRT]
2017-06-20 Power supply feedback resistors placed.
    [Camera.sch, Microcontroller.sch, Miscellaneous.sch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]
2017-06-21 SD card pullups and removed inline resistors. Power labels on camera sheet.
    [Camera.sch, Miscellaneous.sch]
2017-06-24 Added ir cut connector and a few other bits
    [Camera.sch, Microcontroller.sch, Miscellaneous.sch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]
2017-06-24 Results of testing ir switch units in notes doc
2017-06-24 Added proper STM32 part, did most of pinout. Swapped to some cheaper passives, added different microSD socket. Misc cleanup and formatting.
    [Camera.sch, Microcontroller.sch, Miscellaneous.sch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]
2017-06-24 Quick BoM added for pricing checks during dev.
    [stm32-camera-BOM-GroupedByValue.csv]
2017-06-24 Continued development. Added lens mount part. Annotated parts and footprint association.
    [Camera.sch, Microcontroller.sch, Miscellaneous.sch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]
2017-06-24 Started pcb layout tests. Removed fiducials
    [Miscellaneous.sch, stm32-camera.kicad_pcb]
2017-06-25 Part layout tests and changed some pin allocations.
    [Microcontroller.sch, stm32-camera.kicad_pcb]
2017-06-26 Repinned parts of micro to improve routing chances. Part placement, changed footprints etc. Added note in firmware folder to collate thoughts.
    [Camera.sch, Microcontroller.sch, Miscellaneous.sch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]
2017-06-29 Re-added changes from git index corruption issue. Unsure how much recovered.
    [Camera.sch, stm32-camera.kicad_pcb]
2017-07-01 Routing concepts
    [Camera.sch, stm32-camera.kicad_pcb]
2017-07-02 Update loose pcb files
    [stm32-camera.kicad_pcb]
2017-07-07 Update with minor routing changes from laptop
    [stm32-camera.kicad_pcb]
2017-07-09 Footprint changes, using 0805 phototransistor now. Using different headers. Added flash header output. Moved parts around again, silkscreen changes, cosmetics. Routing etc.
    [Microcontroller.sch, Miscellaneous.sch, PowerSupply.sch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]
2017-07-10 Continued messing around with layout
    [stm32-camera.kicad_pcb]
2017-07-13 Routed SD lines and repositioned parts. Re-pinned SD pullup array. Button connected to micro, etc.
    [Microcontroller.sch, Miscellaneous.sch, stm32-camera.kicad_pcb]
2017-07-13 Routing, pours and cosmetic changes. Many general improvements to PCB.
    [stm32-camera.kicad_pcb]
2017-07-14 Routing changes and changed DRC width. Increased min track on board to .2mm. Fixed many DRC errors.
    [Camera.sch, Microcontroller.sch, Miscellaneous.sch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]
2017-07-16 Everything routed. Silkscreen cleanups. Fixed all DRC warnings.
    [stm32-camera.kicad_pcb]
2017-07-18 Added schematic pdf to electronics folder
    [PowerSupply.sch]
2017-07-18 Added RC snubber to address #5.
    [Camera.sch, Microcontroller.sch, Miscellaneous.sch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]
2017-07-18 Final silkscreen pass. Pin labels and branding are negative on soldermask. Let that gold shine through. Closes #6.
    [stm32-camera.kicad_pcb]
2017-07-18 Title blocks and updated notes in schematic pages.
    [Camera.sch, Microcontroller.sch, Miscellaneous.sch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]
2017-07-18 Title block text, removed unused layers in stackup.
    [stm32-camera.kicad_pcb]
2017-07-19 Added gerbers and drills file. Added renders and oshpark validation of correct output.
2018-08-25 Added foundation of firmware. IO mapping, UART/ADC/DAC/UART abstraction mostly handled. Higher level abstractions partially fleshed out. Main task stubs need work.
    [stm32-camera.cfg]
2018-08-25 Streamlined cubemx adc into hal_adc
2018-08-25 Fixed red/green pin def to match hardware
    [status.c]
2018-08-25 Fiddling with build and debugger settings. Updated some notes on debugger setup in readme
    [stm32-camera Debug.cfg]
2018-08-25 Added camer related event defs, signals, timeout defines and counters, and camera task
2018-08-25 Reworked command interface with more functions
    [commands.c]
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2018-08-25 ADC cleanup and validation. Handles photosensor and temp sensors in background.
2018-08-25 Task creation for aux, camera, file system
2018-08-25 Formatting gpio pin/port structure
2018-08-25 Fixed conflicting pin definition for SD Detect and RED led. Closes #9.
    [hal_gpio.c]
2018-08-25 Fix tick timer ifdef for this micro family
2018-08-25 Added missing unicode file for fatfs. Formatting improvements in file system task.
    [sdio.c]
2018-08-25 Added printout of assert message over serial
2018-08-25 Separated powerup state logic from camera reg control. Created hal_camera to act as setup/teardown agent for reset lines etc.
    [hal_camera.c]
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2018-08-25 Added function to get the current clock frequency. Added terminal commands to request clock freq.
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2018-08-25 Fleshed out hal_camera with IO control. Fixed incorrect gpio mode for STROBE pin.
    [hal_camera.c, hal_gpio.c, system_speed.c]
2018-08-25 Terminal log cleanup and correct mask setting by default (all on)
    [commands.c]
2018-08-25 Pullup enabled for button. Removed spare button object from handler.
2018-08-25 Started fleshing out sscb config functions. Removed hardware i2c stubs.
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2018-08-25 Updated DCMI and DMA settings in cubemx to kinda match code
2018-08-25 Fixing warnings/errors from camera driver incomplete code
    [ov2640.c]
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2018-08-25 Added solenoid HAL layer for IO control. Fleshed out ir_filter driver to manage switching states. Added command to get/set filter state.
2018-08-25 Added DMA based read and write to sd io functions. Slow down SD and use hardware flow control.
2018-08-25 Fixed malformed init of 'solenoid' drive causing hardfault when called.
    [app_hardware.c]
2018-08-25 Add filter test toggle to command. Added delay between activating solenoid output and disabling.
2018-08-25 Since the filter works reliably now, remove the rapid toggle arg in cli
2018-08-25 Minor reshuffle of startup order and DMA priority
2018-08-25 filesystem task now uses the filesystem driver to get space and free space on fatfs volume
2018-08-25 Fixed SD not correctly identifying inserted card, which fixed filesystem mounting issues.
2018-08-25 Enable SDIO power saving between commands. Reduced SDIO clock divisor.
2018-08-25 Added system reboot command
    [commands.c]
2018-08-25 Added mount and unmount requests to command handler. Reformatted some file system log strings.
2018-08-25 Slowed SD card speeds down a bit to prevent the occasional glitch during the 10MB copy tests.
    [sdio.c]

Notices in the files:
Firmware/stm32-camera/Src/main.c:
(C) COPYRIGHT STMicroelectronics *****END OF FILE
